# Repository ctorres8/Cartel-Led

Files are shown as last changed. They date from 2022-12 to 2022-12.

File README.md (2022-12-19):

# Cartel-Led
 Proyecto para la materia Técnicas Digitales II. Se trata de un cartel programable que pueda ser utilizado para satisfacer las necesidades básicas de un usuario, como
conocer la fecha y hora actual, la temperatura en el ambiente, o para enunciar a través de él algún mensaje para alertar o informar alguna novedad.

Va a utilizar:
* **Bluetooh:** Para enviar y recibir mensajes
* **SD:** Para recibir mensajes
* **Sensores de luz y temperatura:** Para sensor la luz del ambiente y medir temperatura.
* **RTC:** Reloj en tiempo real para tener la hora y fecha actual.
* **4 Matrices LED 8X8:** Para observar la fecha,hora, temperatura y mensajes recibidos
* **Teclado:** Para una comunicación manual con el cartel.

*El proyecto se encuentra explicado de manera más informativo en el informe (Documentación->informe)* 

# Organización del repositorio:

* **Anteproyecto:** Idea fuerza y presentación del anteproyecto.
* **Datasheets:** Hojas de datos de los componentes utilizados en el proyecto
* **Dristribución de pines:** Distribución de pines y componentes para cada integrante del grupo
* **Documentación:** Informe y manual técnico y de usuario del proyecto
* **Proyecto_Nucleo_Kicad:** Esquemáticos y diseños de PCB
* **Proyecto_STM32:** Código en C con las librerías utilzadas en el proyecto

# Videos de funcionamiento
En el siguiente link se pueden ver algunos videos cortos sobre el funcionamiento del cartel.

Link: https://drive.google.com/drive/folders/1nYiywO-ZSkL0tqdU_d7GqGv7mtErooJ5?usp=share_link

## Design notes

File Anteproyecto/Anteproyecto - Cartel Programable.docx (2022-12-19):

Anteproyecto : Cartel programable led

Idea

Se propone realizar un cartel programable led. En el mismo podrán aparecer los mensajes ingresados por el usuario, marcar la hora y la temperatura del ambiente, entre otras cosas.

Para ello utilizaremos 4 matrices led con conexión SPI de 8x8, siendo un total de 256 leds programables desde el STM.

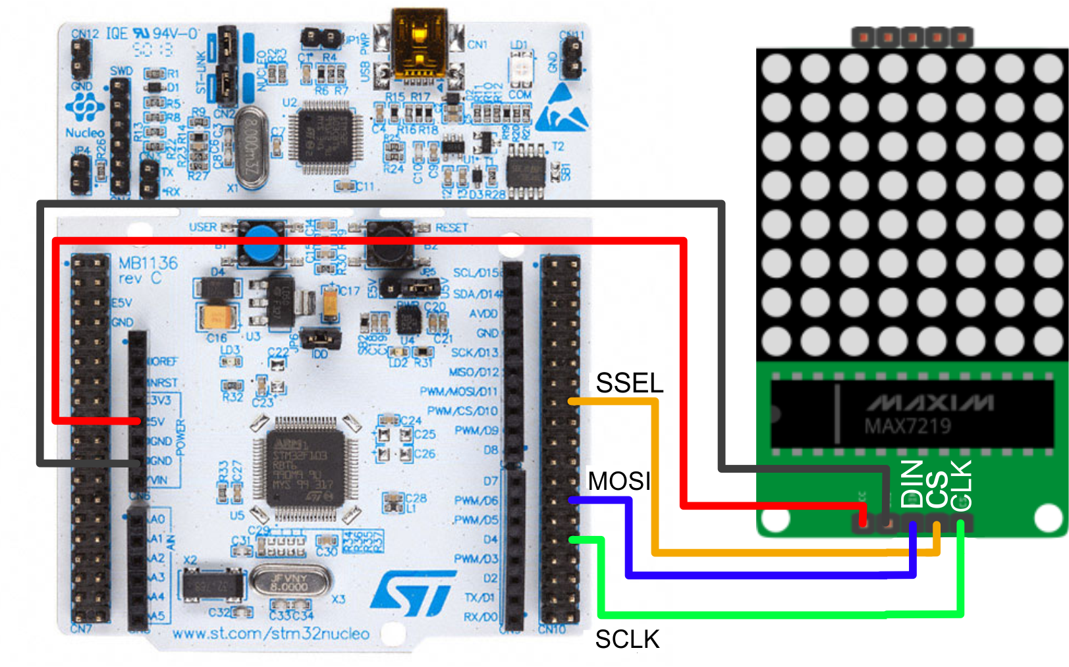
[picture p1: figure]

Los mensajes se podrán levantar desde una SD y a través de bluetooth, que se enviarán por una aplicación de android. Los módulos utilizados serán

- HC-05 para el la recepción de mensajes por Bluetooth,
- MH-SD para leer la uSD.

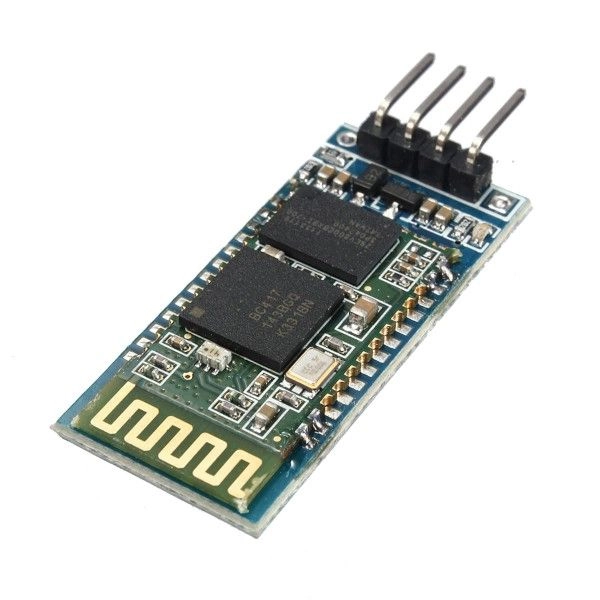
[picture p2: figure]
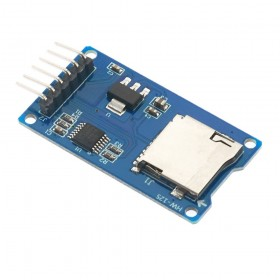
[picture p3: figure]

Módulo HC-05 Módulo MH-SD

3,3-5V 3,3-5V

El sensor para medir la temperatura del ambiente utilizado será el DHT11, DHT22 u otro conveniente que lo evaluaremos en el momento. Algunos ejemplos:

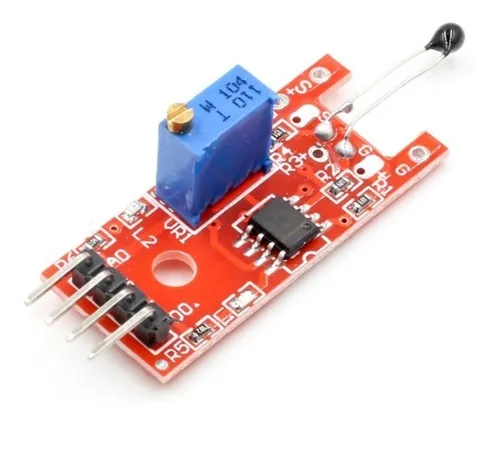
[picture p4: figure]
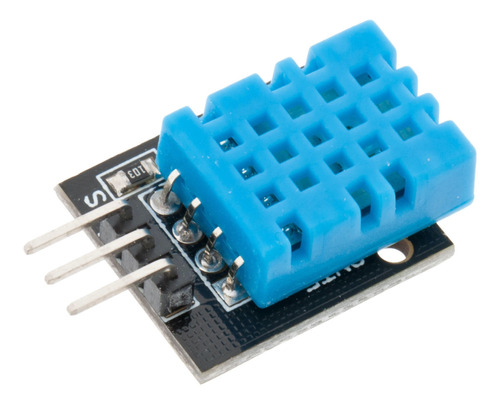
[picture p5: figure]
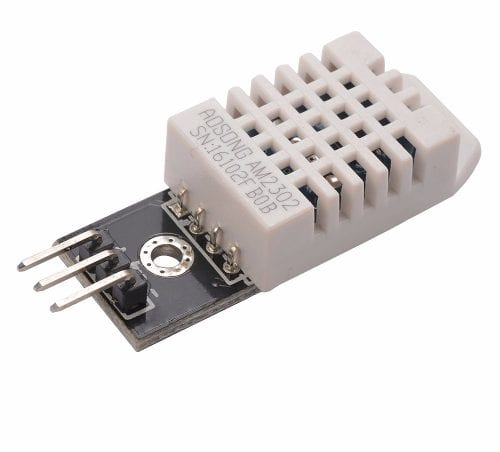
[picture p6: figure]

Sensor con LM393 DHT11 DHT22

3,3-5V 3,3-5V 3,3-5V

También se usará un sensor de luz para determinar la iluminación del ambiente. Se agrega a modo de controlar el brillo del cartel. Comunicación I2C

Módulo Sensor de Luz digital Bh1750.

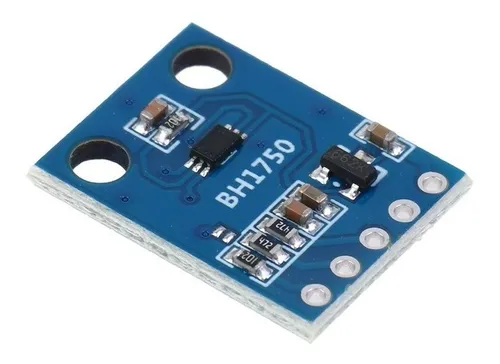
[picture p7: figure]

Bh1750

3.3-5V

Además el cartel contará con un teclado para facilitar la interacción con el usuario.

Diagrama de estados

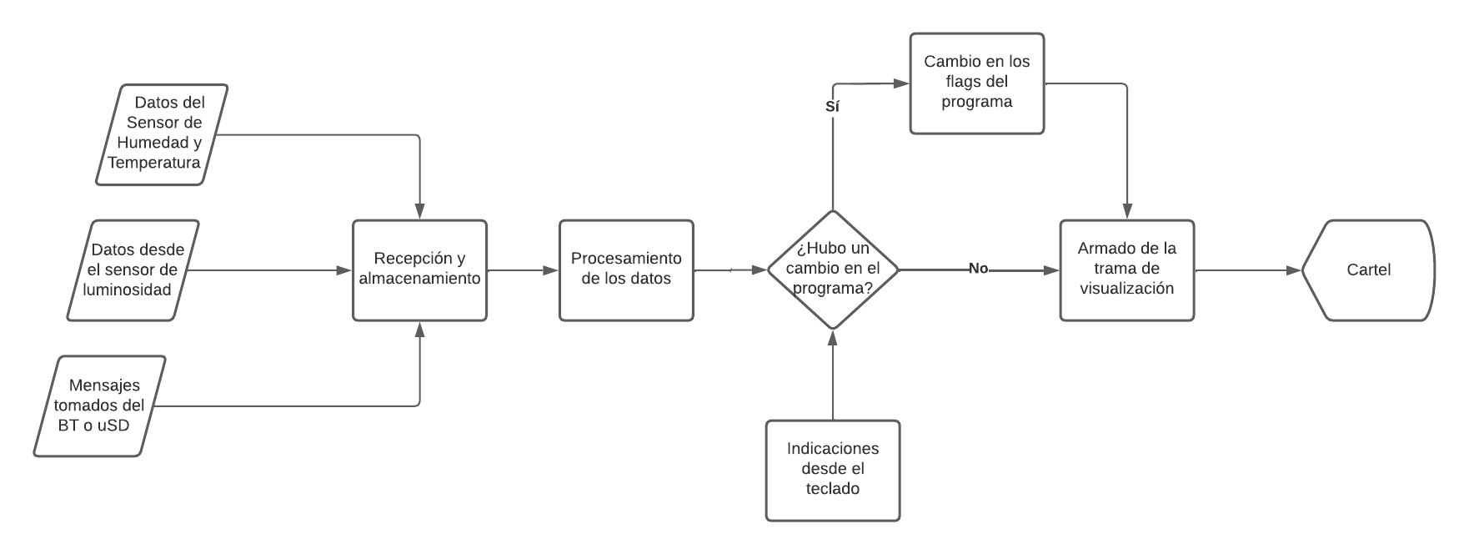
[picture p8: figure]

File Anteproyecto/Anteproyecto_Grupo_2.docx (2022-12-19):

Grupo N°: | 2 | Año y División: | 2022 - R4051
Integrantes: | | 1 – Yujra Jonathan 2 – Argani Ovidio 3 – Torres Cristian
| | | | Fecha:
Título del Proyecto: | | Cartel led programable

Descripción: (Breve explicación de las capacidades, aplicación, funciones y alcances del sistema a desarrollar para evaluar su complejidad y factibilidad de realización)

Se propone realizar un cartel programable led. En el mismo podrán aparecer los mensajes ingresados por el usuario, marcar la hora y la temperatura del ambiente.

Los mensajes se podrán levantar desde una SD y a través de bluetooth, que se enviarán por una aplicación de android.

También se usará un sensor de luz para determinar la iluminación del ambiente, a modo de controlar el brillo del cartel.

Se agregaran 3 botones para alternar desde donde se van a tomar los mensajes, elegir lo que se va a mostrar, configuración, etc.

Especificación Técnica: (Cantidad y tipo de entradas y salidas, tipo de sensores, interfaces de comunicación, interfaz de usuario, rangos de operación, recursos de hardware, funciones, etc.)

Utilizaremos 4 matrices led con conexión SPI de 8x8, siendo un total de 256 leds programables desde el STM.

Los módulos utilizados para la comunicación con SD serán el MH-SD y para el Bluetooth, el HC-05.

El sensor para medir la temperatura del ambiente utilizado será el DHT11, DHT22, LM393 u otro conveniente que lo evaluaremos en el momento

Módulo Sensor de Luz digital Bh1750. Con Comunicación I2C

La alimentación será de 5V, ya que el uC, los sensores y módulos se alimentan con ese voltaje.

Diagrama en bloques: (Diagrama en bloques del sistema con todos los módulos y su interconexión)

SENSOR

DE

TEMPERATURA

BLUETOOTH

STM32F103C8

BLUE PILL

BH1750

SENSOR

DE LUZ

I2C

Matrix 8x8 LED

TARJETA SD

SPI

SPI

Circuito de alimentación con batería

Teclados

Firma y aclaración Representante

UNIVERSIDAD TECNOLÓGICA NACIONAL FACULTAD REGIONAL Buenos Aires Departamento de Electrónica Cátedra: Técnicas Digitales II - Plan 1995 Anteproyecto

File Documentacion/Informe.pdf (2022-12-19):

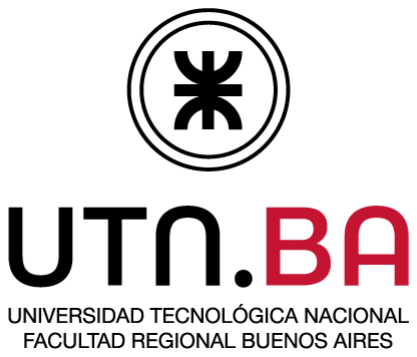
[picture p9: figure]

# Cartel Led Programable

## Trabajo práctico integrador Grupo N° 2

Materia: Técnicas digitales II Profesor: Ing. Juan Alarcón Ayudante: Ing. Marcelo Crivelli

Integrantes | Legajo
Jonathan Yujra | 163647-9
Ovidio Argani | 137715-2
Cristian Torres | 151015-0

# Índice

1. Descripción General | 3
1.1. Introducción | 3
1.2. Interfaz con el usuario | 3
1.3. Operación | 4
2. Hardware | 4
2.1. Diagrama en Bloques | 5
2.2. Circuito esquemático | 5
2.3. Descripción del Circuito | 11
2.4. Circuito Impreso | 12
3. Software | 13
3.1. Software Microcontrolador | 13
3.1.3. Librerías | 14
DEEP BLUE | 14
FatFS - Generic FAT Filesystem Module | 15
3.1.4. Programa Principal | 17
3.1.5. Rutinas de Interrupción | 19
Rutina de recepción/transmisión por Bluetooth | 19
Rutina del teclado | 21
3.1.6. Rutinas Generales | 23
Rutina de la cartel led | 23
Rutina RTC | 25
Rutina Tarjeta Sd | 26
Rutina Sensor de Temperatura y Humedad | 27
Rutina de sensor de luz digital | 28
4. Referencias | 29
Hojas de datos | 29
Manuales | 29
Librerías | 30

# 1. Descripción General

El proyecto se basa en un cartel iluminado programable por el usuario, que contará con distintas funcionalidades y con diferentes tecnologías. El cartel contará con 256 leds que se iluminarán de acuerdo a las peticiones del usuario.
El usuario podrá:
- Establecer y mostrar la fecha
- Establecer y mostrar la hora
- Mostrar la temperatura del ambiente
- Establecer, mostrar y guardar un mensaje.
- Variar la velocidad del mensaje mostrado por el cartel

Para ello, el usuario podrá comunicarse con el cartel a través de comunicación por Bluetooth o con pulsadores que formarán parte del dispositivo.

Entre las tecnologías con las que contará el cartel se encuentran:
- Comunicación Bluetooth
- Reloj en tiempo real
- Sensor de temperatura
- Tarjeta de memoria en formato SD
- Sensor de intensidad lumínica

## 1.1.Introducción

Los carteles siempre han formado y formarán parte de la sociedad. Su utilidad para enunciar un evento, alertar sobre algún peligro, informar alguna novedad son de extrema necesidad para los habitantes que pueden recurrir a ellos de forma práctica y casi al instante.

Para el proyecto de Técnicas Digitales II se propuso la creación de un cartel programable que pueda ser utilizado para satisfacer las necesidades básicas de un usuario, como conocer la fecha y hora actual, la temperatura en el ambiente, o para enunciar a través de él algún mensaje para alertar o informar alguna novedad.

## 1.2.Interfaz con el usuario

Se buscó que la interacción entre el usuario y el dispositivo sea la más práctica y cómoda posible y por eso se recurrió a una comunicación ultra instalada en el ambiente tecnológico como es el bluetooth. El usuario a través de una aplicación podrá conectarse al dispositivo e interactuar con él, ya sea para establecer algún tipo de dato (como la hora y fecha actual o algún mensaje) como también para poder pedirle al cartel que muestre esos datos, la temperatura o algún mensaje.
También se tuvo en cuenta un usuario más acostumbrado a una comunicación más analógica como pueden ser unos pulsadores. Los mismos estarán para cumplir las exigencias mínimas de las personas, como mostrar hora, fecha, temperatura o los mensajes.
El cartel estará conformado por 256 leds ubicados en forma de matriz(8x32) que mostrarán el mensaje de derecha a izquierda.
El cartel también cuenta con un sensor de luz que hará de acompañante visual, ya que elevará la iluminación del cartel si se encuentra en un ambiente demasiado iluminado (exteriores) como también reducirá la iluminación del mismo si el ambiente se encuentra oscuro (lugares cerrados, subsuelos).

## 1.3.Operación

El modo de operación es sencillo. El usuario a través de una aplicación podrá comunicarse con el cartel y enviar datos o mensajes que se reproducirá en el dispositivo. Tendrá una opción usuario normal y una pensada para trabajos de mantenimiento, donde a través de unas macro se podrán testear diferentes funciones y controlar el buen funcionamiento del mismo.

El usuario también podrá optar por usar unos pulsadores que forman parte del dispositivo para también comunicarse con él.

# 2. Hardware

Para la construcción del cartel se utilizó una placa física donde se interconectaron los diferentes sensores y módulos para el armado final del dispositivo. Entre los módulos y sensores utilizados se encuentran:

- 4x Matrix led de 8x8 puntos
- STM32 NUCLEOF401-RE
- Módulo Bluetooth HC06
- Sensor de luz BH1750
- Sensor de temperatura DHT11
- Lector de tarjetas SD

La placa física será alimentada con 5V y con un regulador de voltaje de 5V a 3,3V para alimentar algunos sensores.

## 2.1.Diagrama en Bloques

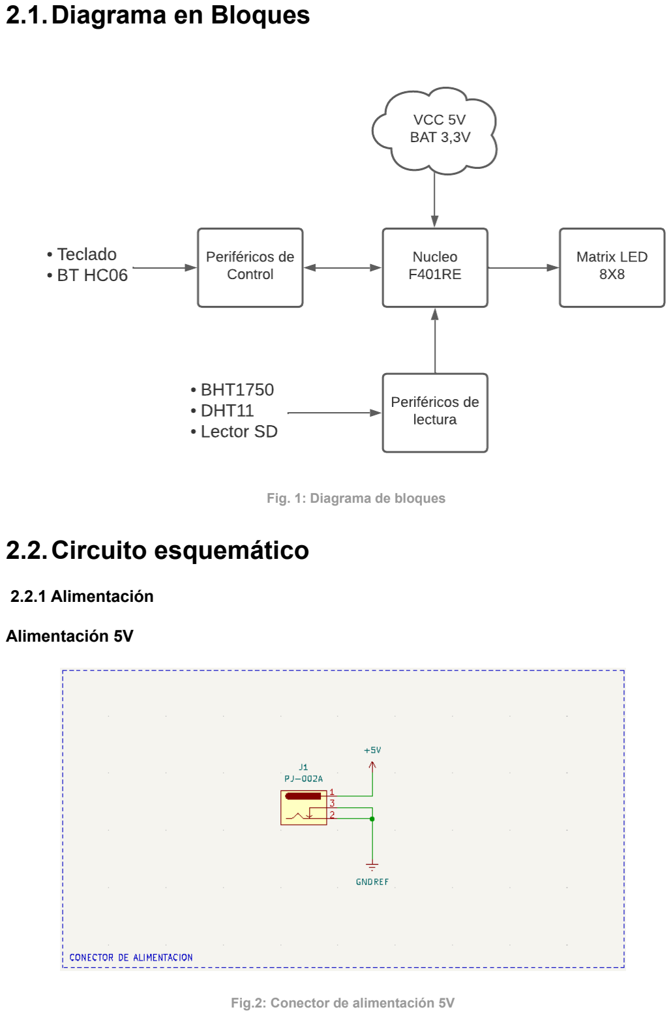
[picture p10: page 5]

Fig. 1: Diagrama de bloques

## 2.2.Circuito esquemático

### 2.2.1 Alimentación

Alimentación 5V

Fig.2: Conector de alimentación 5V

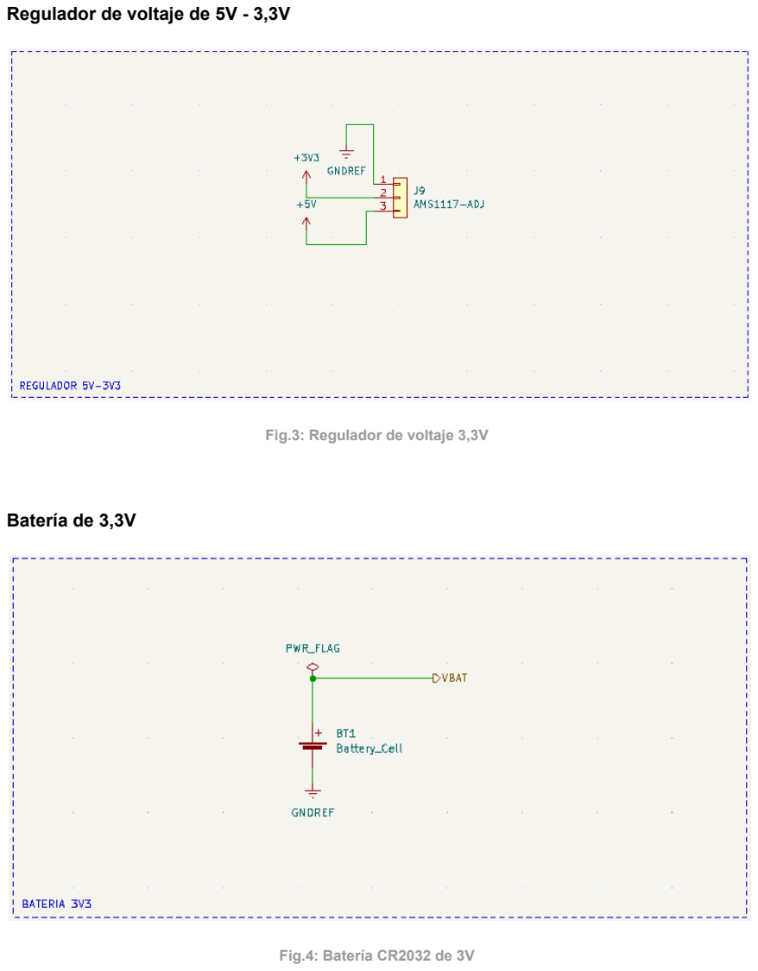
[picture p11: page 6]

Regulador de voltaje de 5V - 3,3V

Fig.3: Regulador de voltaje 3,3V

Batería de 3,3V

Fig.4: Batería CR2032 de 3V

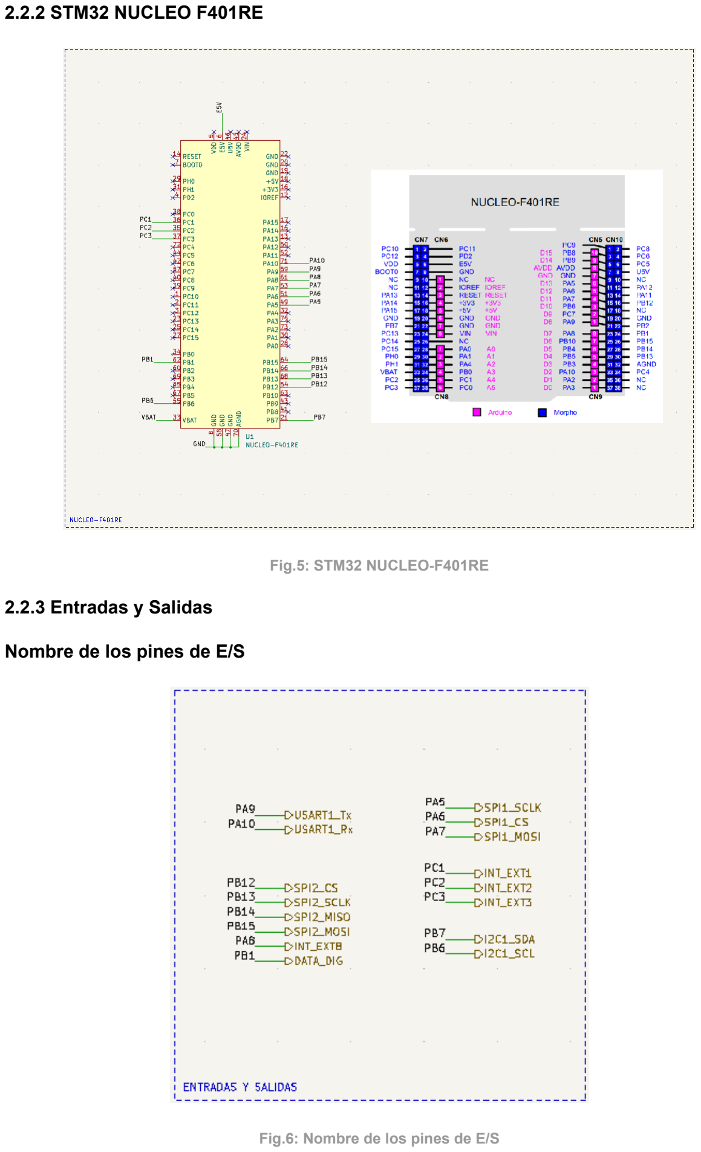
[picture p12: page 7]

### 2.2.2 STM32 NUCLEO F401RE

Fig.5: STM32 NUCLEO-F401RE

### 2.2.3 Entradas y Salidas

Nombre de los pines de E/S

Fig.6: Nombre de los pines de E/S

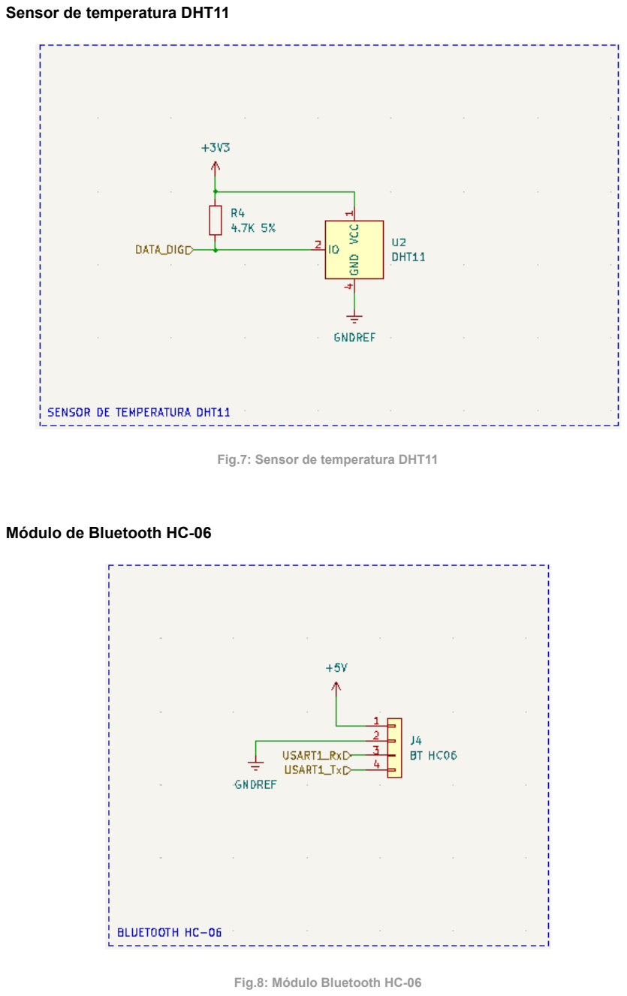
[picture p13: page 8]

Sensor de temperatura DHT11

Fig.7: Sensor de temperatura DHT11

Módulo de Bluetooth HC-06

Fig.8: Módulo Bluetooth HC-06

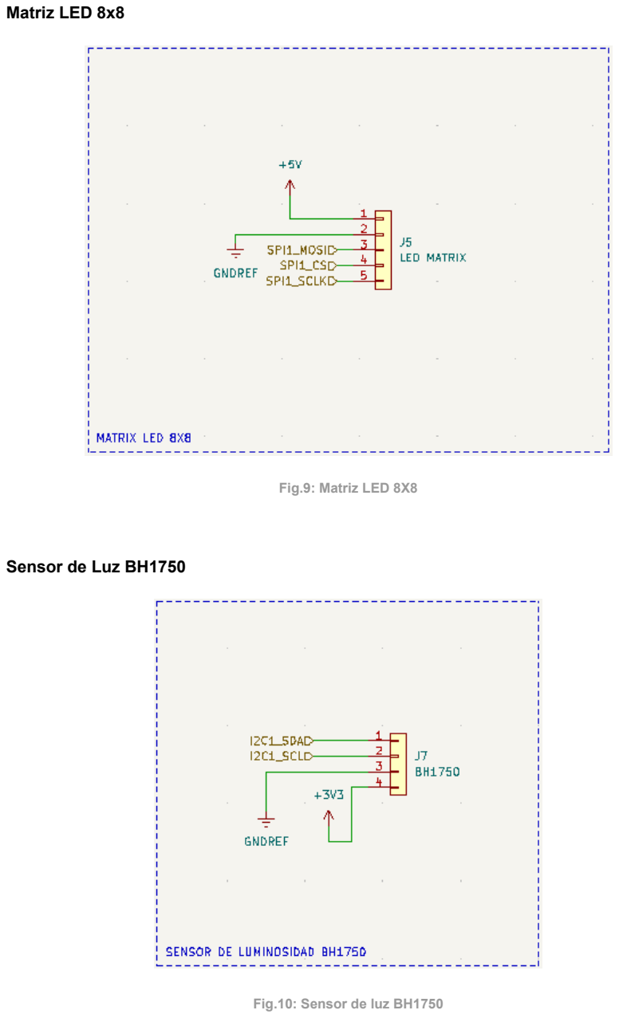
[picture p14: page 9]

Matriz LED 8x8

Fig.9: Matriz LED 8X8

Sensor de Luz BH1750

Fig.10: Sensor de luz BH1750

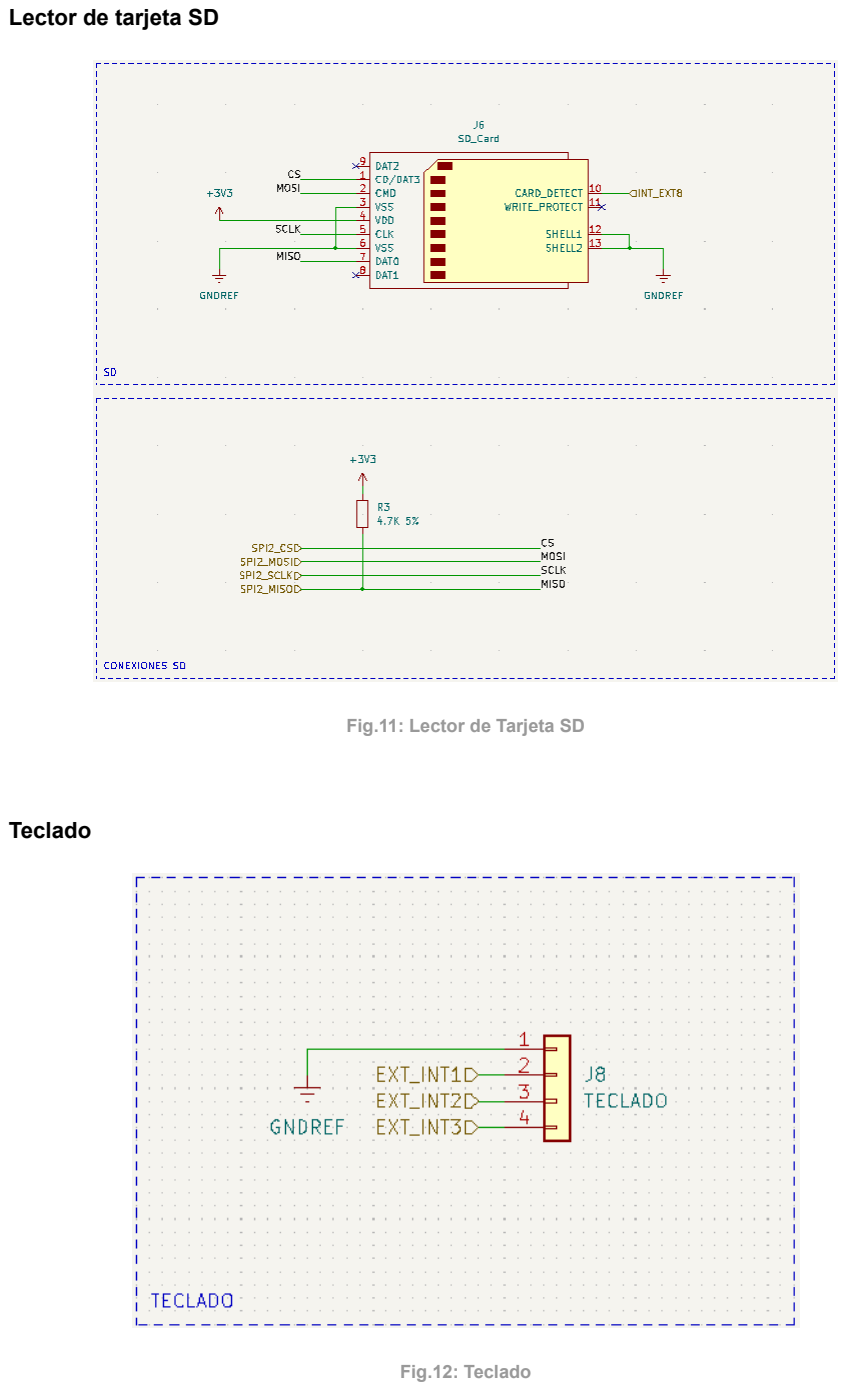
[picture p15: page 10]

Lector de tarjeta SD

Fig.11: Lector de Tarjeta SD

Teclado

Fig.12: Teclado

## 2.3.Descripción del Circuito

El circuito está alimentado por una tensión continua de 5V y también cuenta con un regulador de voltaje de 5V a 3,3V. La NUCLEO F401RE además estará alimentada por una batería de 3,3V CR2032 que servirá para alimentar las funciones básicas de la placa como el reloj en tiempo real y que de ese modo no pierda la cuenta.

La distribución de la alimentación en los componentes es la siguiente:

Los componentes alimentados a 5V son los siguientes:

- NUCLEO F401RE
- BT HC-06
- 4x Matriz LED 8X8

Los componentes alimentados a 3,3V son los siguientes:

- Lector SD
- BH1750
- DHT11

## 2.4.Circuito Impreso

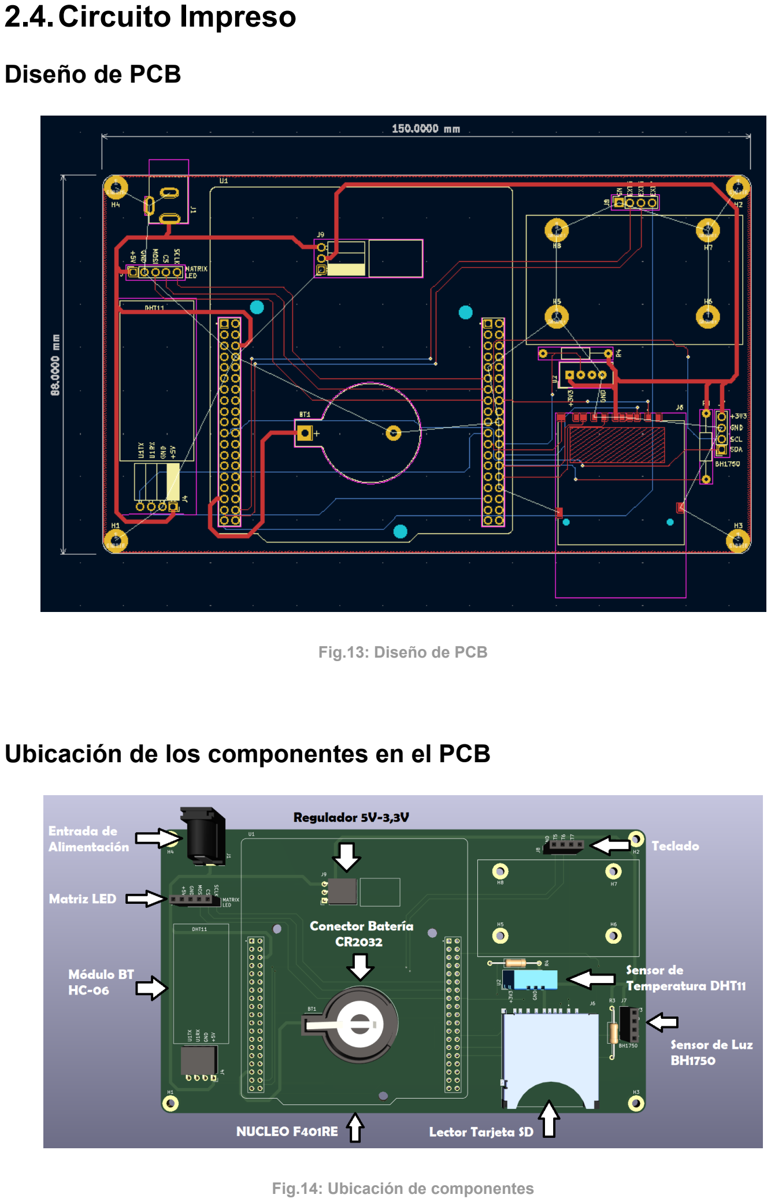
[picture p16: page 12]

### Diseño de PCB

Fig.13: Diseño de PCB

### Ubicación de los componentes en el PCB

Fig.14: Ubicación de componentes

# 3. Software

## 3.1.Software Microcontrolador

En el proyecto se utilizaron los siguientes protocolos de comunicación:

- SPI para la comunicación con la SD y la matrix LED
- I2C para la comunicación con el sensor de luz BH1750 y el sensor de temperatura DHT11
- Comunicación Serie para la comunicación con el módulo de BT HC06.

Cada uno de los módulos tuvo sus pines dedicados para asegurar la correcta transferencia de información.

Para el manejo de tiempo se utilizaron timers y RTC. El RTC para guardar la fecha y hora en el micro, teniendo en cuenta de que estas no se pierdan en caso de que el micro sea desconectador la tensión de alimentación ya que está también alimentado por una batería externa.

Se utilizaron Timers para controlar:

- Sistema operativo (FreeRTOS)
- DHT11
- Rutina de la Matrix Led

El teclado cuenta con 3 botones que fueron configurados como interrupciones externas.

El diagrama principal se encuentra en el apartado 3.1.4.

### 3.1.1. Entorno de desarrollo

El proyecto fue enteramente desarrollado en el IDE que nos provee ST, el STM32CUBE IDE y el lenguaje de programación utilizado fue en su totalidad el C.

### 3.1.2. Sistema Operativo

Se utilizó un sistema operativo en tiempo real (FREERTOS) por su practicidad con los manejos de tarea ya que su planificador es del tipo preemtive, los que nos permite organizar las tareas según su prioridad.

El RTOS (y su planificador) cuenta con un timer dedicado a que se ejecute su planificación.

### 3.1.3. Librerías

DEEP BLUE

Se utilizaron librerías externas para el módulo de matriz Led 8x8 y el IC MAX7219, dichas librerías fueron realizadas para la gente de DEEP BLUE.

DOT_MATRIX.h

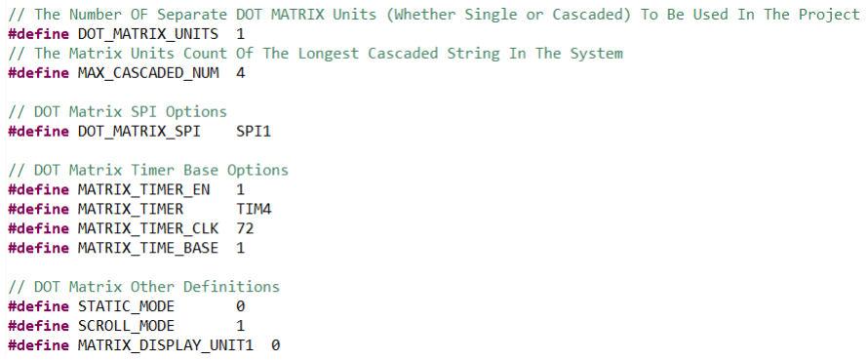
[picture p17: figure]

Fig.15: Bloque de código DOT_MATRIX.h

En la imagen de arriba se observan los diferentes defines donde se configura la cantidad de módulos en cascada, el número de SPI de la placa NUCLEO y el timer de interrupción.

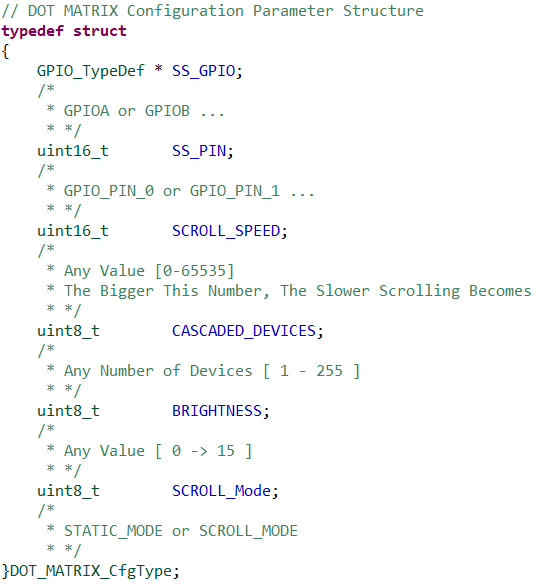
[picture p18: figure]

Fig.16: Struct de configuración de los módulos Matriz Led

Dentro de la estructura DOT_MATRIX_CfgType se pueden administrar la velocidad de corrimiento, la iluminación y los pines dedicados.

Las prototipos de funciones de la librería encargada administrar la funciones internas de del módulo son las siguientes:

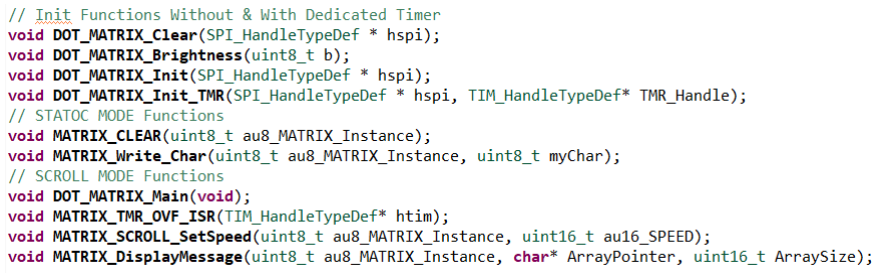
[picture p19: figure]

Fig.17: Prototipos de funciones utilizados en la librería

En la siguiente variable del tipo struct perteneciente a DOT_MATRIX_cfg.c se define el pin de Chip Select, la velocidad inicial (en milisegundos) y el brillo por defecto.

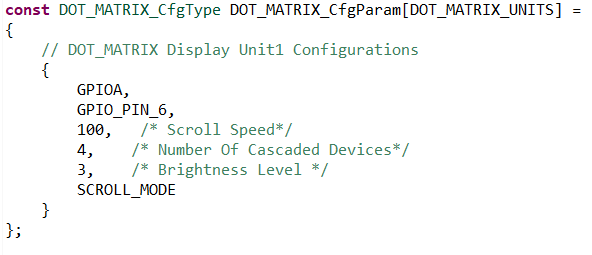
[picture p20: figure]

Fig.18: Configuración Default de los módulos Matriz Led

Los enlaces a las librerías se encuentran en el apartado de referencias.

Alexander Hoffmanes

La librería externa del BH1750 creada por Alexander Hoffmanes, es sencilla. De ella usamos la inicialización del sensor de luz digital:

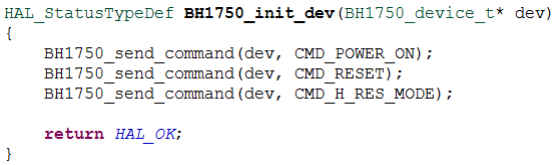
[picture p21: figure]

En donde se envían comandos por I2C para configurar el sensor a una resolución de 1 lux.

Luego para las mediciones usamos la función:

La cual lee el valor sensado por el módulo BH1750, luego lo convierte a unidades de lux.

FatFS - Generic FAT Filesystem Module

FatFs es un módulo de sistema de archivos FAT/exFAT genérico para pequeños sistemas integrados. Está escrito totalmente en C y en una capa completamente separada de la capa de E/S del disco. Fue desarrollada por chaN.

FatFs controla los dispositivos de almacenamiento a través de una sencilla interfaz de acceso a los medios que se muestra a continuación.

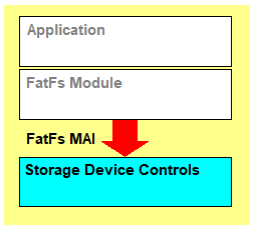
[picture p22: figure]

Fig.19: Abstracción de la librería

Las librerías que incluye el paquete son:

- diskio.h: Encargada de la interfaz de disco de bajo nivel (E/S)
- ff.h: módulo de archivos de sistema FAT
- ffconf.h: Configuraciones funcionales FatFs

Los archivos .C que incluye el módulo son:
- ff.c: código del módulo de archivos de sistema FAT
- ffsystem.c: código de funciones dependientes del SO para FATFs
- ffunicode.c: tablas de conversión para diferentes lenguajes.
- mmc_stm32f1_spi.c: código de control del modo SPI

El enlace a la librería se encuentra en el apartado de referencias.

### 3.1.4. Programa Principal

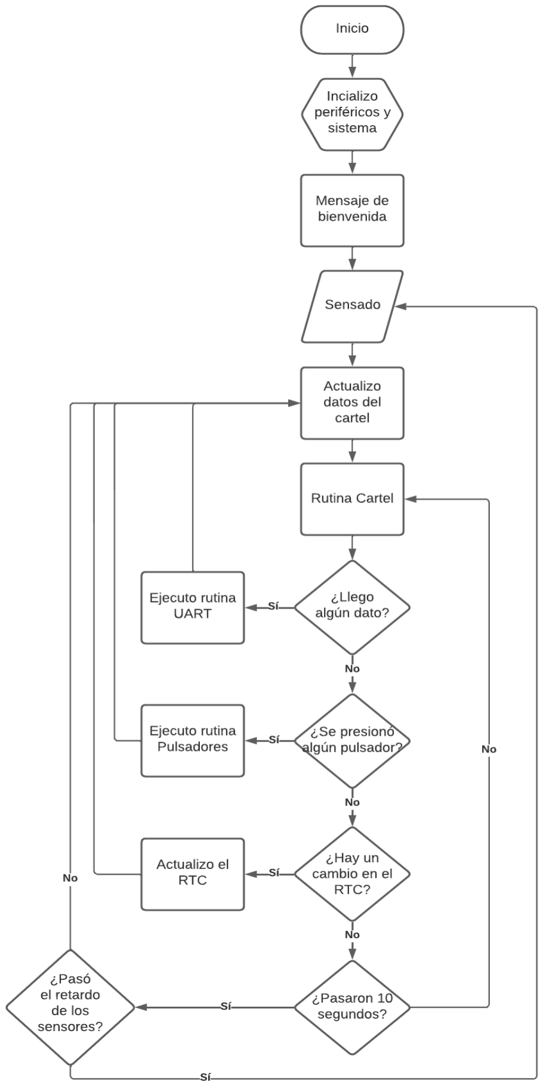
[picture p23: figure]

Fig.20: Diagrama de flujo general del sistema

El programa está enteramente diseñado en freertos, que tiene la particularidad de ejecutar un número prediseñado de tareas al mismo tiempo, por lo que el diagrama de flujo de arriba es una aproximación de lo que sucede en realidad. Al ejecutarse las tareas por orden de prioridad y al tener cada una un tiempo de ejecución distinto es difícil pensar en que el sistema tenga algún tipo de previsibilidad.

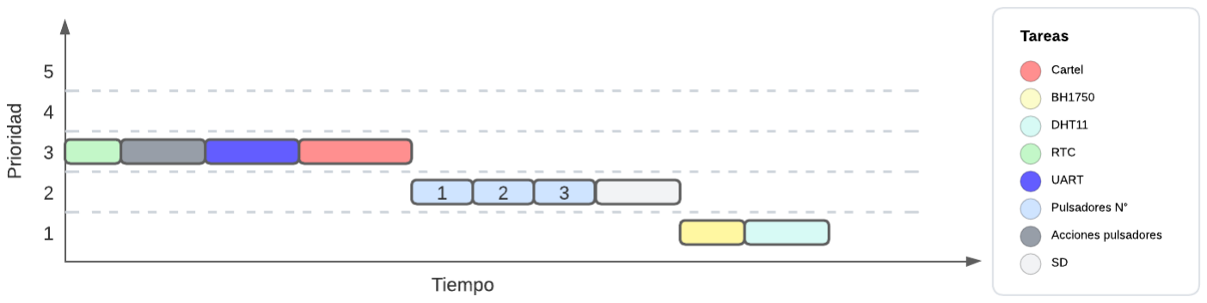
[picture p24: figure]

Fig.21: Diagrama de prioridad

En la imagen de arriba se ve como fue diseñado el planificador y la prioridad que se le dio a las tareas. Cabe destacar que la más importantes para nuestro criterio fueron:
- Tarea Cartel: donde se encarga de la manipulación de los mensajes en la matriz led
- Tarea UART: donde una vez recibido el mensaje por bluetooth se procede a separarlo y darle una función dependiendo del mensaje recibido.
- Tarea RTC: donde el reloj actualiza la hora y fecha actual.


Fig.22: Inicialización de tareas

En la imagen de arriba se puede observar la inicialización de tareas del RTOS cuyo orden de prioridad decrece a medida que el número de prioridad crece.


Fig.23: Inicialización de periféricos

### 3.1.5. Rutinas de Interrupción

Rutina de recepción/transmisión por Bluetooth

Fig.24: Diagrama de flujo tarea Bluetooth

La rutina de recepción por Bluetooth se hace en forma de interrupción y a través de comunicación serie. Cuando llega un nuevo mensaje el programa deja lo que está haciendo y va a atender el pedido de iniciar la recepción del mensaje. Mientras recibe, sigue ocupándose en las demás tareas. La HAL encargada de administrar eso es:

La HAL recibe 3 parámetros:
- El puntero a la uart
- El vector donde se van a guardar los datos
- Y el valor máximo de recepción.

HAL_UARTEx_ReceiveToIdle_IT permite recibir una cantidad máxima de datos predefinida en el parámetro Size, como también si llega a un estado Idle (es decir, porque el largo de la trama era mucho más chico que el valor máximo propuesto y encontró un fin de cadena en el medio), también puede cortar la recepción y avisar que terminó de recibir.

Una vez terminado de recibir los datos, dependiendo del tipo de mensaje recibido, el micro puede:
- Actualizar el valor de la hora y fecha en el RTC.
- Devolver un mensaje si lo que se está pidiendo es algún dato.
- Guardar un mensaje enviado por el usuario.

Rutina del teclado


Fig.25: Diagrama de flujo tarea teclados

El teclado consiste en tres pulsadores conectados a la NUCLEO F401RE en forma de interrupción externa. Cada pulsador tiene su propia tarea y sub rutina encargado de modificar algún aspecto que afecte a lo que se muestra en la matriz de led.

Subrutina pulsador 1:
El pulsador 1 uno controlará los modos en que se mostrarán los datos en el cartel.
- El modo normal, el cartel mostrará la fecha, la hora y la temperatura cada 10 segundos, cada uno
- Si se presiona una vez, el cartel mostrará solo la fecha ininterrumpidamente.
- Si se presiona por segunda vez, el cartel mostrará solo la hora ininterrumpidamente.
- Si se presiona por tercera vez, el cartel mostrará solo la temperatura ininterrumpidamente.
- Si se vuelve a presionar volverá al modo normal

Subrutina pulsador 2:
El pulsador 2 mostrará el mensaje cargado en el dispositivo a través del bluetooth o del SD.
- Si se presiona una vez, el cartel mostrará el mensaje cargado por el Bluetooth.
- Si se presiona por segunda vez, el cartel mostrará el mensaje cargado por el SD.
- Si se presiona por tercera vez, el cartel volverá al modo normal.

Subrutina pulsador 3:
El pulsador 3 variará la velocidad en la que los datos se desplazan en el cartel.
- Si se presiona una vez, el cartel tendrá una velocidad baja.
- Si se presiona por segunda vez, el cartel tendrá velocidad media.
- Si se presiona por tercera vez, el cartel tendrá velocidad alta.
- Si se vuelve a presionar, volverá a velocidad baja.

### 3.1.6. Rutinas Generales

Rutina de la cartel led


Fig.26: Diagrama de flujo tarea cartel led

El cartel led se actualiza cada cierta cantidad de milisegundos, cuando termina este tiempo, el mensaje del cartel se desplaza una posición a la izquierda. La función encargada de este desplazamiento es:

Cuando se modifica el mensaje a mostrar se apagan todos los leds de los módulos y empieza a escribir el nuevo mensaje por medio de la función. La función que apaga los leds de los módulos es:

Si se presiona el pulsador 3 cambia la velocidad del desplazamiento del cartel.

Rutina RTC


Fig.27: Diagrama de flujo tarea RTC

El RTC se encarga de mantener la cuenta de la hora y fecha actual en todo el sistema. Aún si el dispositivo se encuentra desenchufado, el RTC sigue funcionando debido a que está siendo alimentado por una batería CR2032.

Su funcionamiento es simple y casi imperceptible, cuenta segundos,minutos,horas y fechas. Cuando ocurre algún cambio, actualiza los datos del cartel. Su cuenta puede ser modificada o actualizada a través del Bluetooth.

Rutina Tarjeta Sd


Fig.28: Diagrama de flujo tarea SD

Cuando el usuario seleccione este modo se tendrá que chequear si hay una tarjeta sd insertada, caso contrario se pedirá por el cartel que se inserte una. Si hubiera tarjeta insertada se procede a inicializar y pasar a modo sd.

Cuando se encuentre en el modo sd los mensajes se cargaran a partir de la tarjeta sd. Los mensajes estarán alojados dentro de un archivo llamado "mensajes.txt". La particularidad de este modo es que los mensajes del usuario contenidos dentro del archivo se cargarán de forma cíclica.

Por ejemplo: Si tuviera un solo mensaje, sería el único en mostrarse. Pero, si tuviera dos o más, se mostraran de a uno con una duración predeterminada, y siempre de forma cíclica. Se considera un mensaje a una línea del archivo de texto. El modo sd se encarga automáticamente de actualizar el buffer del cartel.
A continuación un ejemplo del contenido del archivo.

Fig.29: Creación de mensajes

En el caso de que se retire la tarjeta o se cambie de modo se retorna al estado inicial.

Rutina Sensor de Temperatura y Humedad


Fig.30: Diagrama de flujo tarea Sensor de temperatura DHT11

El sensor DHT11 es un dispositivo que capta la temperatura y la humedad del ambiente. Su forma de recibir es en formato serie, empezando por la humedad y luego por la temperatura.

La comunicación entre el microprocesador y el DHT11 y su sincronización se hace a través de un solo bus de datos de 40bits.

El formato de datos es:

8 bits de datos de humedad para enteros + 8 bits de datos de humedad para decimales + 8 bits de datos enteros de temperatura + 8 bits de datos decimales de temperatura + 8 bits de paridad.

La inicialización del DHT11 se hace a través de:

Las lecturas se hacen a través de de la tarea DHT11 con la función:

Rutina de sensor de luz digital


Fig.31: Diagrama de flujo tarea sensor de luz BH1750

La rutina del sensor de luz BH1750 se ejecuta por medio de la comunicación I2C cada 10 segundos, la función encargada de leer el valor y convertirlo a unidades de lux es:

En esta función se ejecutan 2 funciones más:

- BH1750_read_dev(dev): Se encarga de leer 2 bytes que sensa el módulo BH1750
- BH1750_convert(dev): Se encarga de unir los 2 bytes y dividirlo por 1,2 para convertirlo a lux

Una vez que terminó de convertir a unidades de lux, se determina el brillo de la matriz led:

- Si la iluminación es alta, el brillo de la matriz será alta
- Si la iluminación es baja, el brillo de la matriz será baja

La configuración de la intensidad del brillo se hace mediante la función:

DOT_MATRIX_Brightness(i); // Siendo i un valor del 1 al 10

# 4. Referencias

Hojas de datos

Sensor de luz BH1750: Link Datasheet (https://drive.google.com/file/d/1hNUBCfKHLAi73L5wXrpIC9SqpSZIVXO_/view?usp=share_link)

Sensor de temperatura DHT11: Link Datasheet (https://drive.google.com/file/d/1Tri0Ij8wTlMghaLgcgkP-QxAEPVwCSko/view?usp=share_link)

Módulo Bluetooth: Link Datasheet (https://drive.google.com/file/d/1JlVVr95fDBjWHLqKieN57tqQwmHvouif/view?usp=share_link)

Regulador de tensión LM1117: Link Datasheet (https://drive.google.com/file/d/1GX2ReR8_QrMDlmroXhPoYFuI4F_l6q0y/view?usp=share_link)

Matriz Led 8x8: Link Datasheet (https://drive.google.com/file/d/1PQreYGPisMozHs944OEVEkRimML9rfyi/view?usp=share_link)

IC Max7219: Link Datasheet (https://drive.google.com/file/d/1aTzSAUG9kioTlt8-OvNlfmLg9X7Mt-0M/view?usp=share_link)

SD: Link Datasheet (https://drive.google.com/file/d/1bB_GbcPMbwC02TCU_5XH0IdrR9Pr8sX0/view?usp=share_link)

Manuales

STM32 NUCLEO F401RE: Reference Manual (https://drive.google.com/file/d/1pSwSPJOKQf2tx9QKM_nUZqD4yKAoJSJ0/view?usp=share_link)

STM32 NUCLEO F401RE: User Manual (https://drive.google.com/file/d/1CUA2DkAZa6mUlTmTVMNTtc7Z68Vzk2mZ/view?usp=share_link)

Librerías

Deep Blue Librería y proyecto: Link WEB (https://deepbluembedded.com/stm32-max7219-dot-matrix-display-interfacing-library/) Librería Descarga: Link Descarga (https://drive.google.com/file/d/17-EFMTJjTC_MbU3OdnbpxqhBEf7X1ldC/view) Proyecto ChaN FATFS: Link WEB (http://elm-chan.org/fsw/ff/00index_e.html)

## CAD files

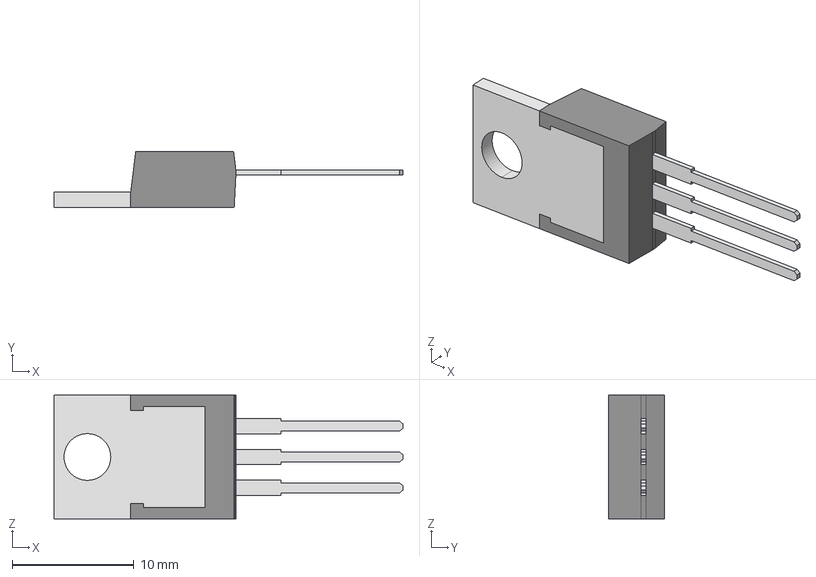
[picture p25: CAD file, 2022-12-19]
Proyecto_Nucleo_KiCAD/modelos3d/LM1117T.stp
28.7 x 4.57 x 10.2 mm
T03B_BODY
T03B_LEAD x 3
T03B_HS

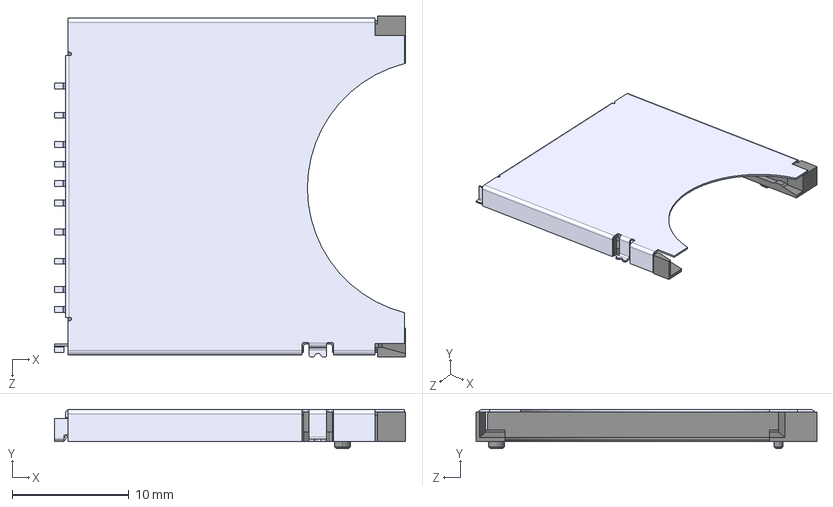
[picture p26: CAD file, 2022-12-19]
Proyecto_Nucleo_KiCAD/modelos3d/3D_SD_GSD09002SEU.step
30.1 x 3.35 x 29.2 mm

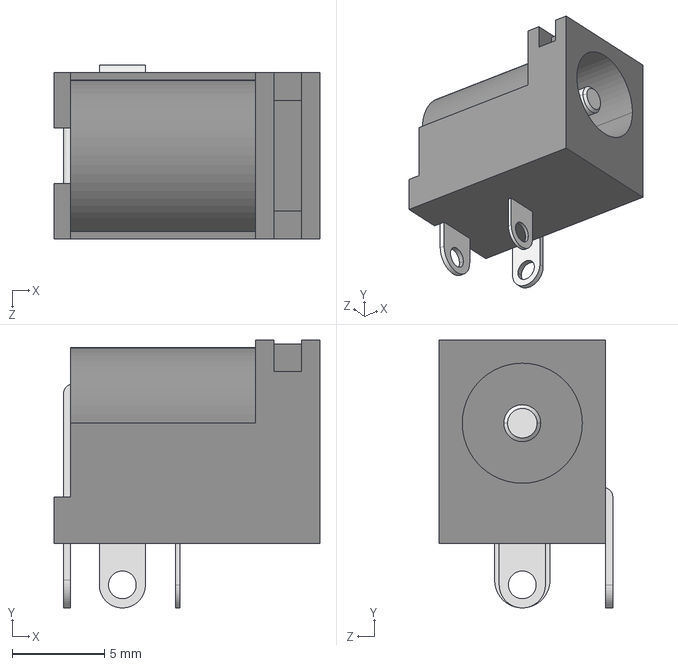
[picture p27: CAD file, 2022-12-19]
Proyecto_Nucleo_KiCAD/modelos3d/PJ-002A.step
14.4 x 14.5 x 9.40 mm

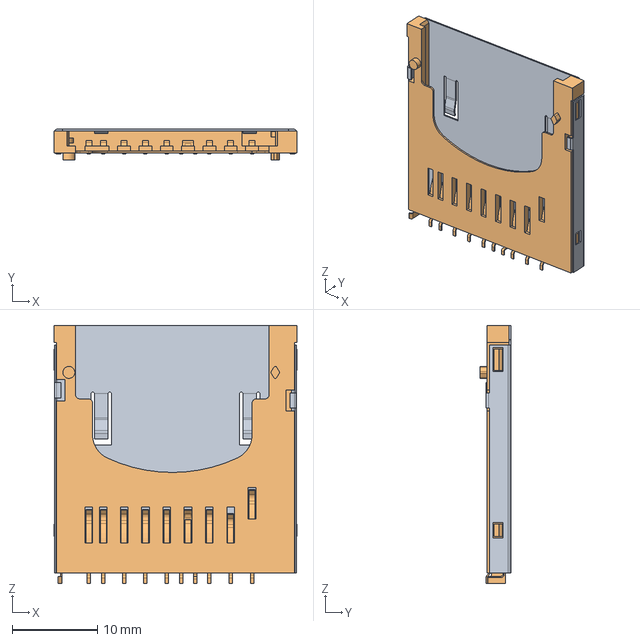
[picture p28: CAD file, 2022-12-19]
Proyecto_Nucleo_KiCAD/modelos3d/10067847-001RLF.stp
28.4 x 3.60 x 30.3 mm
PRT0003
PRT0005

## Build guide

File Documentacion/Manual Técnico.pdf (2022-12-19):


# Cartel Led Programable

## Manual Técnico

Técnicas Digitales II

Integrantes

Jonathan Yujra

Ovidio Argani

Cristian Torres

# Índice

1. Herramientas necesarias | 3
2. Consideraciones de seguridad | 3
3. Diagramas | 4
3.1 Diagrama de bloques | 4
3.2 Esquemáticos | 4
3.3 Ubicación de los componentes en la placa | 10
4. Características Eléctricas | 10
5. Solución de problemas | 11
6. Soporte técnico | 12

# 1. Herramientas necesarias

Para el armado/desarmado del dispositivo y su posterior arreglo es necesario que cuente con las siguientes herramientas.

- Destornillador
- Multímetro
- Soldador
- Desoldador
- Fuente de 5V
- Cable microUSB a USB
- etc.

# 2. Consideraciones de seguridad

Antes de desarmar el dispositivo verifique que se encuentra desconectado a la red eléctrica.

No lo sacuda, podría desconectar los módulos que tiene dentro.

El dispositivo cuenta con una batería interna que alimenta al microcontrolador, antes de analizar el estado de los componentes es posible que tenga que retirar la batería para evitar algún falso contacto.

El dispositivo cuenta con una placa de desarrollo y varios módulos, cada uno se encuentra señalado en la placa, al igual que el pin por donde entra su correspondiente alimentación. Si necesita medir tensión ubique primeramente los pines señalados en la placa.

Tenga en cuenta que el dispositivo no cuenta con ningún tipo de interruptor, una vez que sea conectado a la red eléctrica el dispositivo quedará alimentado.

El dispositivo recibe 5V de tensión de entrada, no lo alimente con otro tipo de tensión, podría dañar los componentes.

# 3. Diagramas

## 3.1 Diagrama de bloques

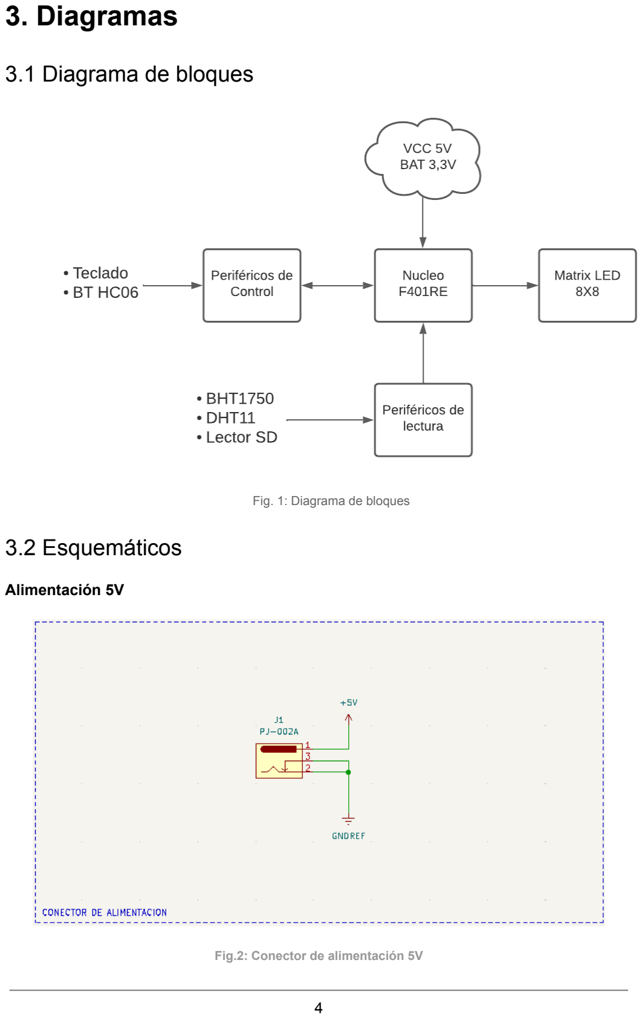
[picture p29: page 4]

Fig. 1: Diagrama de bloques

## 3.2 Esquemáticos

Alimentación 5V

Fig.2: Conector de alimentación 5V

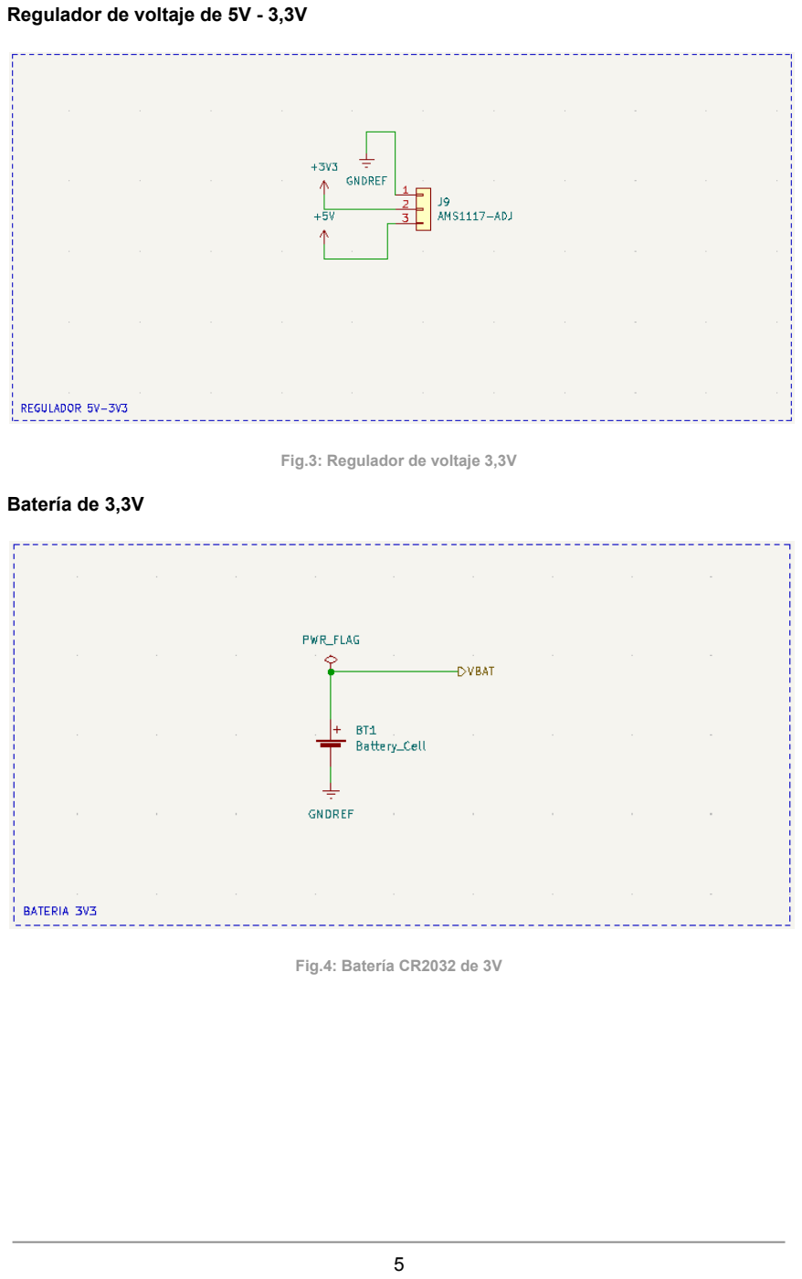
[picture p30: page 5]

Regulador de voltaje de 5V - 3,3V

Fig.3: Regulador de voltaje 3,3V

Batería de 3,3V

Fig.4: Batería CR2032 de 3V

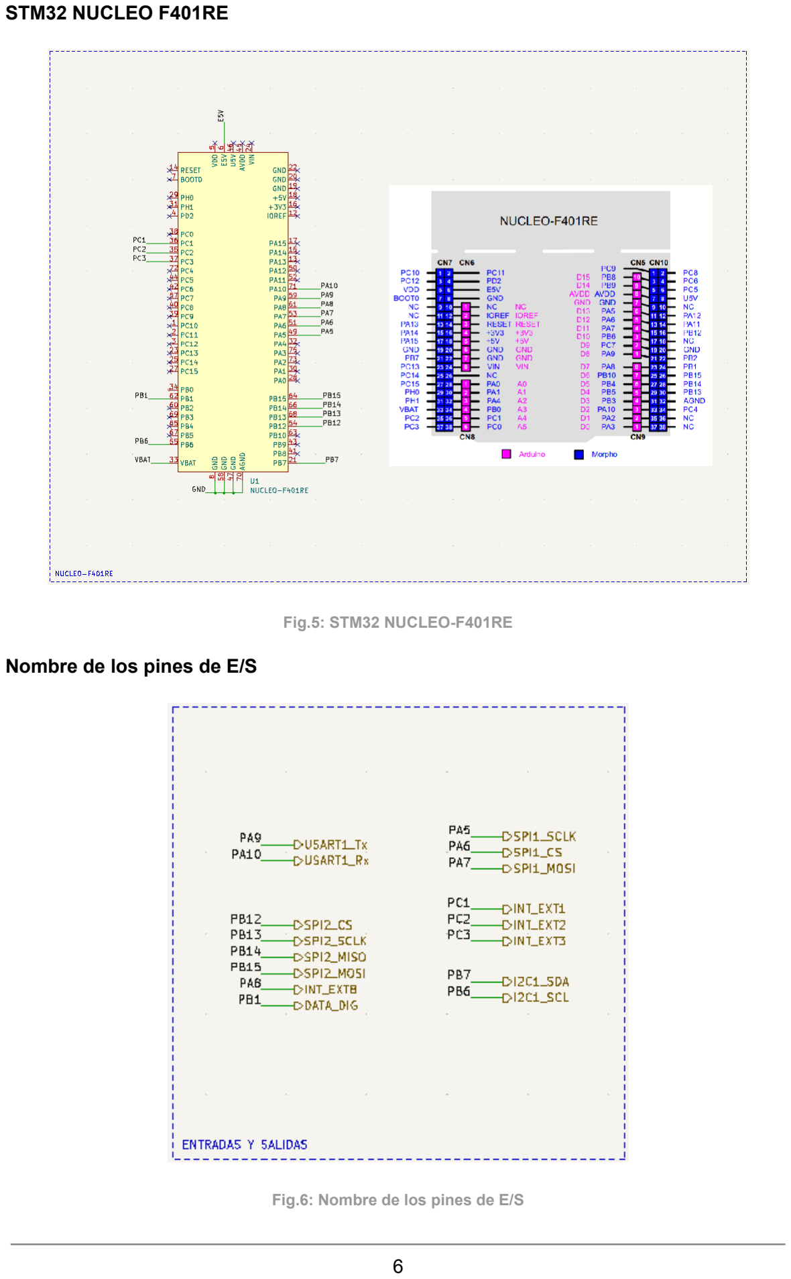
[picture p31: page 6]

STM32 NUCLEO F401RE

Fig.5: STM32 NUCLEO-F401RE

Nombre de los pines de E/S

Fig.6: Nombre de los pines de E/S

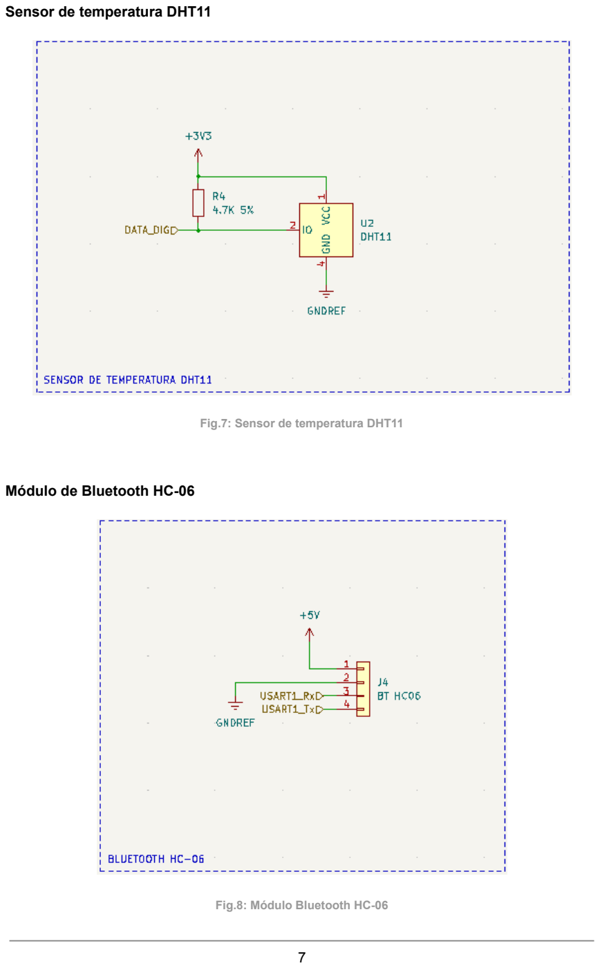
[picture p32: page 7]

Sensor de temperatura DHT11

Fig.7: Sensor de temperatura DHT11

Módulo de Bluetooth HC-06

Fig.8: Módulo Bluetooth HC-06

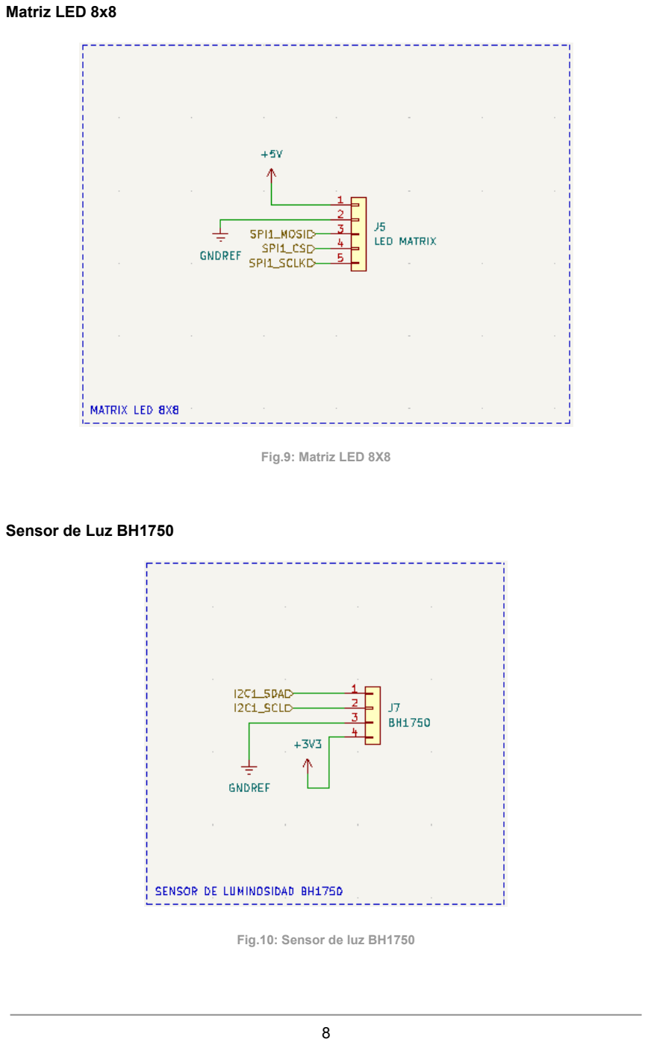
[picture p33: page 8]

Matriz LED 8x8

Fig.9: Matriz LED 8X8

Sensor de Luz BH1750

Fig.10: Sensor de luz BH1750

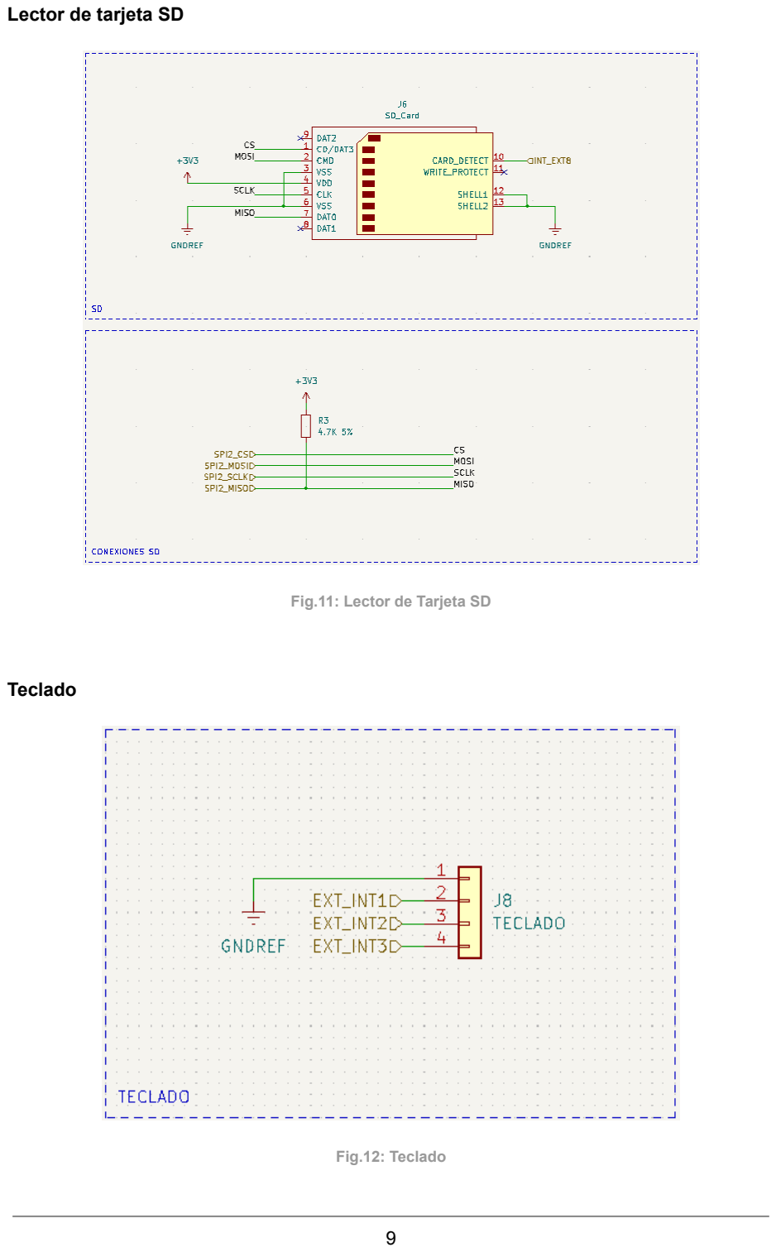
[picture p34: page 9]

Lector de tarjeta SD

Fig.11: Lector de Tarjeta SD

Teclado

Fig.12: Teclado

## 3.3 Ubicación de los componentes en la placa

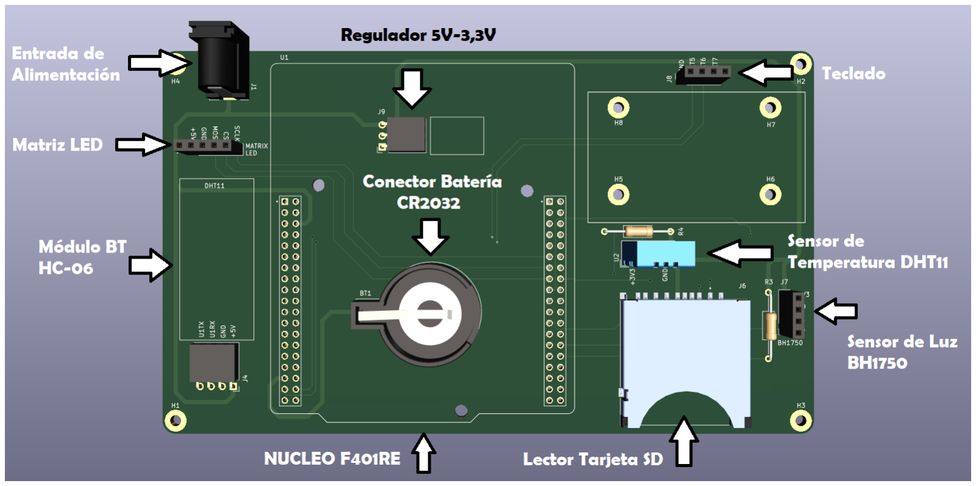
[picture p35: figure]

Fig.13: Ubicación de componentes

# 4. Características Eléctricas

### Valores máximos

Componente | Tensión [V] | Corriente[mA]
Matriz Led | 6 | 500
BH1750 | 4,5 | 7
Regulador LM1117 | 20 | 800
DHT11 | 5,5 | 0,3
Lector SD | 3,6 | 200
BT HC-06 | 5,2 | 40
Corriente Maxima Consumida | | 1547,30 mA

### Valores Normales

Componente | Tensión [V] | Corriente[mA]
Matriz Led | 5V | 330
BH1750 | 3,3V | 0,2
Regulador LM1117 | 5V | 5
DHT11 | 3,3V | 0,1
Lector SD | 3,3V | 100
BT HC-06 | 5V | 8
Corriente media | | 443mA

# 5. Solución de problemas

No funciona el sensor o algún módulo en particular. Verifique que esté recibiendo el voltaje correspondiente.

Se pierde la cuenta del reloj cuando se desenchufa de la red.
Es posible que la batería se haya quedado sin carga, cámbiela.

Los pulsadores no presionan de manera correcta.
Es posible que estén obstruidos o por hayan sido aplastados con fuerza, cámbielos.

El Lector SD no funciona de manera correcta.
Es posible que se haya presionado con fuerza y que se haya desoldado, verifique su soldadura.

El sensor de temperatura no funciona correctamente.
Es posible que haya estado expuesto a altas temperaturas, verifique si sus voltajes son óptimos.

### Comandos de testeo

Los siguientes comandos de testeo sirven para configurar y comprobar el buen estado del sistema. Puede enviar los comandos por la aplicación ATYAPP o enviarlos a través de un puerto serie.

Comando | Función
ATYO | Devuelve un OK por BT.
ATYM | Devuelve el último mensaje de anuncio cargado en el cartel
ATYFdd-mm-aaaa | Configura la fecha dd/mm/aaaa en el cartel
ATYHhh:mm:ss | Configura la hora hh:mm:ss en el cartel
ATYf | Devuelve la fecha por BT
ATYh | Devuelve la hora por BT
ATYT | Devuelve la temperatura que marca el sensor por BT

Enviar los comandos a través de la aplicación ATYAPP:
Para enviar los comandos a través de la aplicación ATYAPP puede escribir los comandos en el sector de mensajes. Siguiendo los siguientes pasos:
1. Asegúrese que el módulo HC-06 se encuentra conectado.
2. Verifique si el dispositivo se encuentra alimentado a 5V.
3. Conéctese al dispositivo a través de la aplicación ATYAPP
4. Escriba el comando en el sector de mensajes y presione ENVIAR.

Enviar los comandos a través del puerto serie:
Para enviar los comandos a través del puerto serie debe utilizar los pines USART1 TX (D8) y para recibir una respuesta USART1 RX (D2). Como están señalados en la imagen de abajo:

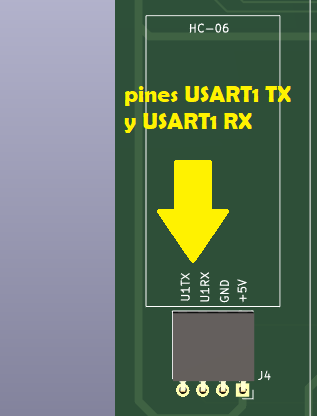
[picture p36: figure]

Fig. 14: Ubicación de los pines USART1 TX Y USART1 RX

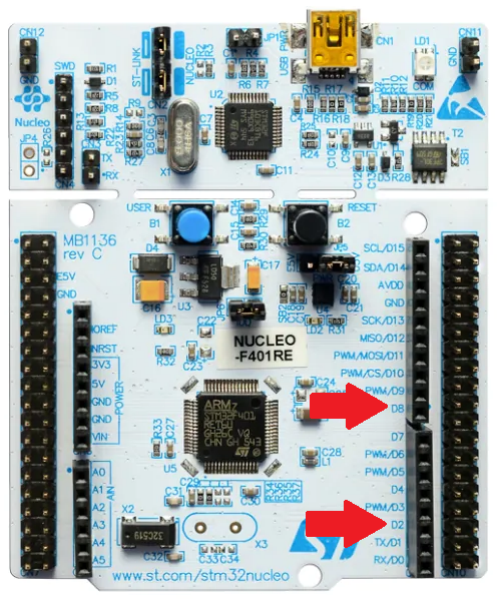
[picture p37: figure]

Fig. 15: Ubicación de los pines (D8) USART1 TX Y (D2) USART1 RX

# 6. Soporte técnico

Para contactarse con el soporte técnico puede comunicarse a:

Teléfono: xxxxxxxxxxx

Email: soportetecnico@gmail.com

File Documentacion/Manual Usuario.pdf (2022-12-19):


# Cartel Led Programable

## Manual de usuario

Técnicas Digitales II

Integrantes

Jonathan Yujra

Ovidio Argani

Cristian Torres

# Índice

Alimentación | 3
Encendido del dispositivo | 6
Funcionamiento | 7
Configuración a través de la Aplicación ATY app | 7
Configuración a través del teclado | 7
Rutina Modo 1: | 8
Rutina Modo 2: | 8
Rutina Modo 3: | 8
Apagado del dispositivo | 9
Soporte Técnico | 10
Solucionador de problemas | 10

# Alimentación

El dispositivo funciona a 5V. Para poder encenderlo necesita un transformador de 220V/5V AC-DC que pueda suministrar 5V al aparato. Pueden utilizarse cualquier tipo de cargador de smartphone que entregue a la salida esa salida de tensión. Precaución: Hay cargadores de carga rápida que entrega más de 5V a su salida, si utiliza esos cargadores podría ocasionar daños al dispositivo, recomendamos fijarse bien su salida antes de conectarlo.

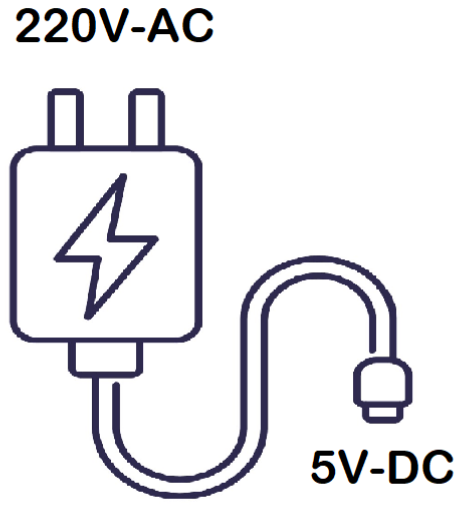
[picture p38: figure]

Fig.1: Transformador de 220V a 5V

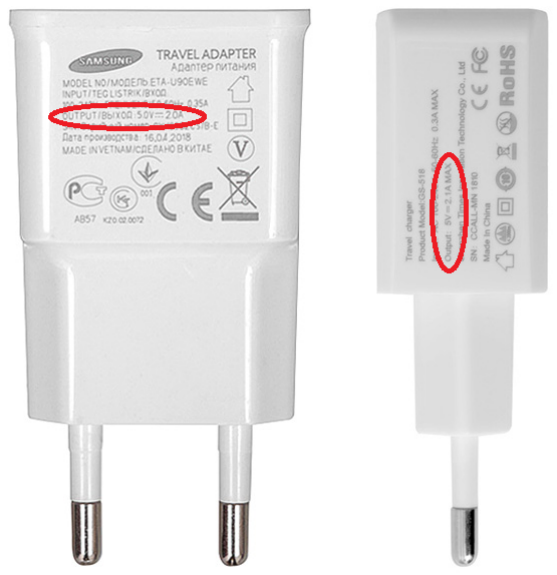
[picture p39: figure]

Fig.2: Ejemplo de transformador

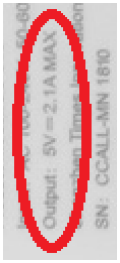
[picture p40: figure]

Fig.2: Datos transformador

Nota:

El aparato trae una batería interna que cumple la función de no apagar el reloj propio del sistema. No la retire.

# Encendido del dispositivo

El dispositivo se encenderá apenas se alimente. Una vez que enchufe el transformador el dispositivo iniciará mostrando un mensaje de bienvenida en la pantalla. Luego de unos segundos se procederá a ejecutar el MODO 1 (Ver el apartado de Funcionamiento para más detalles).

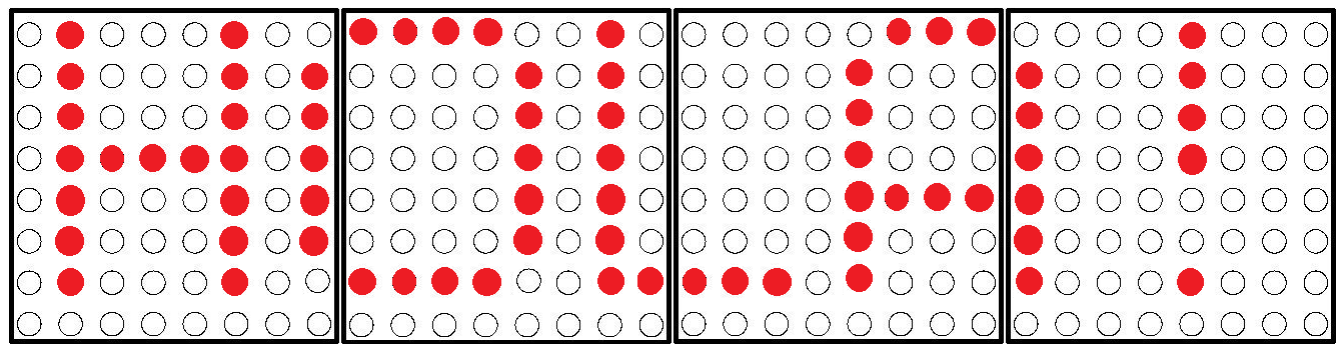
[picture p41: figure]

Fig.3: Mensaje de bienvenida en el cartel

El dispositivo tiene una rutina predeterminada: mostrará la fecha y hora que tuvo desde que fue actualizado de fábrica por última vez. Para actualizar o cambiar algún parámetro vea el apartado de funcionamiento del dispositivo.

# Funcionamiento

El dispositivo cuenta con una app disponible para Android y que puede descargarse desde la Play Store y que permitirá configurar el dispositivo como desee. También puede configurar el funcionamiento con los 3 botones que forman parte del aparato.

## Configuración a través de la Aplicación ATY app

La aplicación le permitirá, entre otras cosas, sincronizar la hora y la fecha actual de su smartphone con el dispositivo.

- Presione el botón “Ajustar Fecha” y/o “Ajustar Hora” para poder actualizar el reloj del sistema.
- Presione “Mensaje” para enviar un mensaje al dispositivo.
- Presione “Modo” para elegir entre los diferentes modos de funcionamiento del dispositivo.

## Configuración a través del teclado

El cartel cuenta con tres pulsadores con diferentes funciones para que se pueda modificar el funcionamiento sin necesidad de un dispositivo externo.

- Presione el pulsador 1 para cambiar los modos de funcionamiento del dispositivo.
- Si presiona 1 vez el cartel mostrará solo la fecha.
- Si presiona 2 veces el cartel mostrará solo la hora.
- Si presiona 3 veces el cartel mostrará la temperatura en el ambiente.
- Si vuelve a presionar el pulsador 1 vuelve a la rutina predeterminada.
- Presione el pulsador 2 para mostrar los mensajes cargados en el dispositivo
- Si presiona 1 vez el cartel mostrará el mensaje enviado por Bluetooth.
- Si presiona 2 veces el cartel mostrará el mensaje cargado desde la tarjeta SD.
- Si vuelve a presionar el pulsador 2 vuelve a la rutina predeterminada.
- Presione el pulsador 3 para cambiar la velocidad en la que el cartel muestra los mensajes.
- Si presiona 1 vez el cartel mostrará en una velocidad lenta
- Si presiona 2 veces el cartel mostrará en una velocidad media
- Si presiona 3 veces el cartel mostrará en una velocidad rápida
- Si vuelve a presionar el pulsador 3 volverá a la velocidad lenta

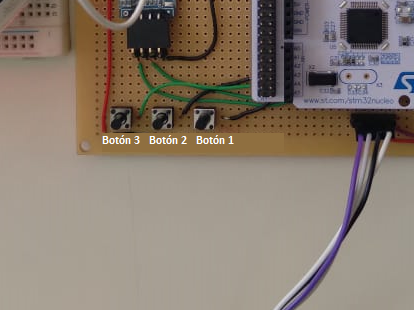
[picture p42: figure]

Fig. 4: Número de botones

Rutina predeterminada

El dispositivo cuenta con una rutina predeterminada ni bien es alimentado con 5V. La rutina consta de 3 mensajes que se muestran en la pantalla a velocidad media, y que se repiten en el siguiente orden:

1) Fecha
2) Hora
3) Temperatura

### Rutina Modo 1:

Cuando se selecciona el modo 1, el cartel solo mostrará la fecha.

### Rutina Modo 2:

Cuando se selecciona el modo 2, el cartel solo mostrará la hora.

### Rutina Modo 3:

Cuando se selecciona el modo 3, el cartel solo mostrará la temperatura.

# Apagado del dispositivo

Para apagar el dispositivo desconecte el aparato de la red eléctrica, la hora y la fecha no se perderán debido a la batería interna que tiene el dispositivo. Los mensajes cargados si se perderán. Cuando el cartel vuelva a estar enchufado el dispositivo mostrará nuevamente el mensaje de bienvenida seguido de la rutina predeterminada.

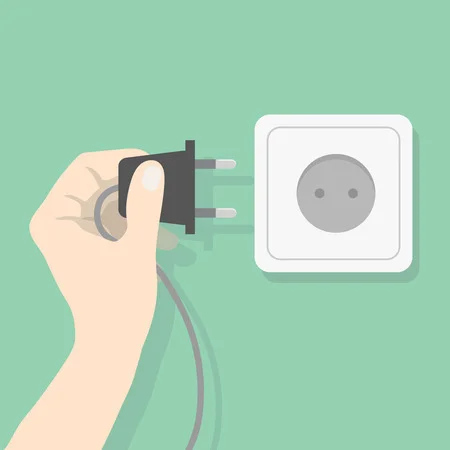
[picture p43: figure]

Fig. 5: Desconexión del transformador

# Soporte Técnico

## Solucionador de problemas

El dispositivo tiene una iluminación muy baja.

Es posible que el sensor de luz esté tapado por algún cuerpo u objeto.

El dispositivo tiene una iluminación muy alta.

Es posible que el ambiente esté muy iluminado o el sensor de luz esté siendo iluminado con una luz externa.

El dispositivo mide una temperatura muy alta

Es posible que el dispositivo esté cerca de una fuente de calor que impida al sensor de temperatura hacer una lectura fidedigna de la temperatura ambiente.

El dispositivo no cambia de mensaje a mostrar.

Presione el botón 1 para cambiar de modo de rutina o contacte al servicio técnico.

El dispositivo no guarda la hora y la fecha cuando se apaga.

El dispositivo puede haberse quedado sin batería interior. Cámbiela o contacte al servicio técnico.

Dadas las siguientes condiciones: detenga todo tipo de operación de inmediato. Desenchufe la unidad y contacte al centro de servicio técnico.

- Hay un fuerte ruido dentro del aparato
- Se emiten olores durante la operación
- El dispositivo calienta mucho
- El dispositivo fue expuesto al agua o a una fuente de calor.
- Calor anormal en el cable de suministro eléctrico o en el enchufe.

Teléfono Servicio técnico: 11-xxxx-xxxx

Email Servicio Técnico: serviciotecnico@gmail.com

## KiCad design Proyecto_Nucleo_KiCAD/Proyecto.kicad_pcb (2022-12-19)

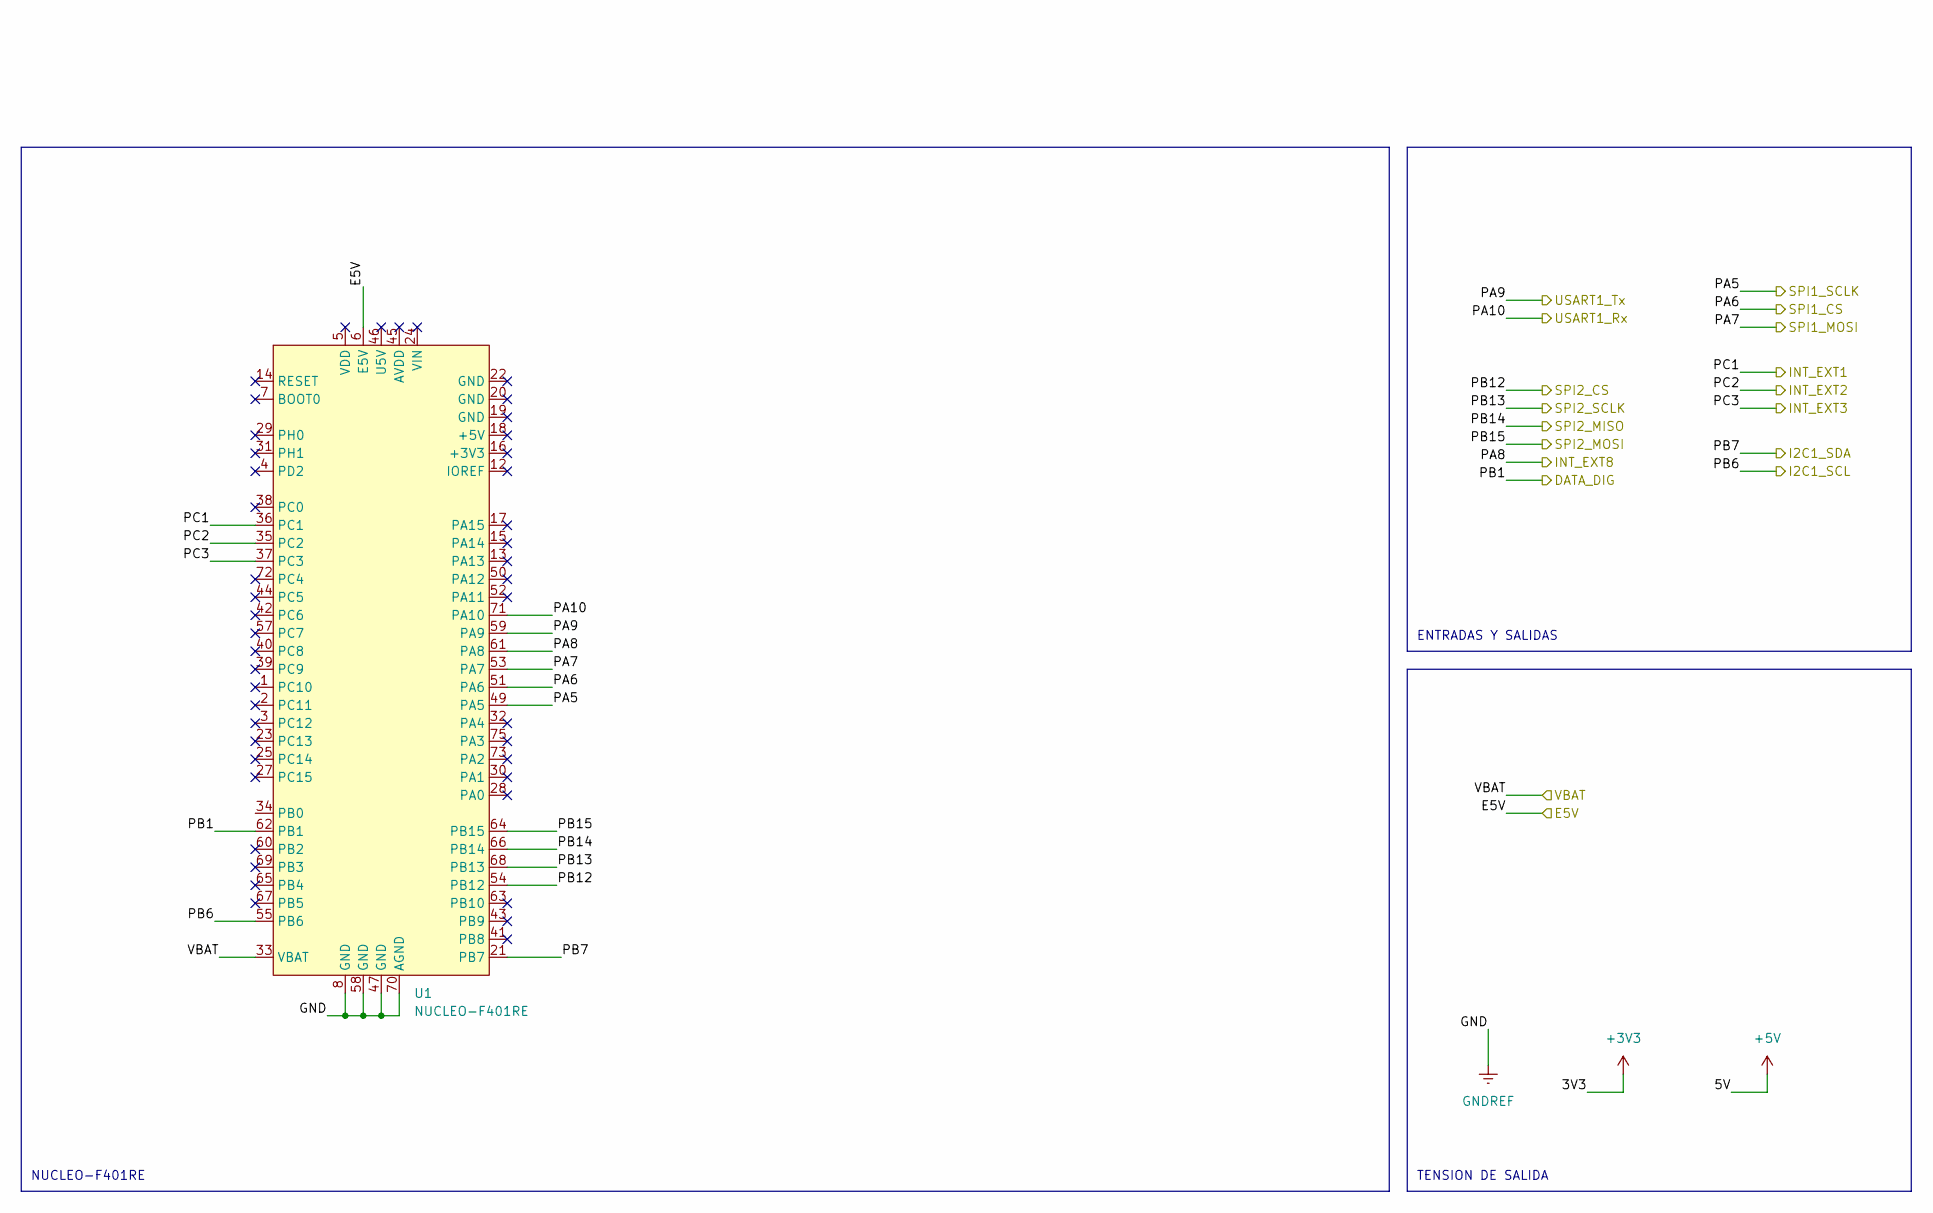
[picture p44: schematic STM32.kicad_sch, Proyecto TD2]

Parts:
U1: NUCLEO-F401RE; ST_NUCLEO-F401RE

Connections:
+5V: U1.6 (E5V); also elsewhere on the board
/EntradasSalidas/CS: U1.54 (PB12); also elsewhere on the board
/EntradasSalidas/MISO: U1.66 (PB14); also elsewhere on the board
/EntradasSalidas/MOSI: U1.64 (PB15); also elsewhere on the board
/EntradasSalidas/SCLK: U1.68 (PB13); also elsewhere on the board
/STM32/PA5: U1.49 (PA5); also elsewhere on the board
/STM32/PA6: U1.51 (PA6); also elsewhere on the board
/STM32/PA7: U1.53 (PA7); also elsewhere on the board
/STM32/PA8: U1.61 (PA8); also elsewhere on the board
/STM32/PA9: U1.59 (PA9); also elsewhere on the board
/STM32/PA10: U1.71 (PA10); also elsewhere on the board
/STM32/PB1: U1.62 (PB1); also elsewhere on the board
/STM32/PB6: U1.55 (PB6); also elsewhere on the board
/STM32/PB7: U1.21 (PB7); also elsewhere on the board
/STM32/PC1: U1.36 (PC1); also elsewhere on the board
/STM32/PC2: U1.35 (PC2); also elsewhere on the board
/STM32/PC3: U1.37 (PC3); also elsewhere on the board
/STM32/VBAT: U1.33 (VBAT); also elsewhere on the board
GNDREF: U1.8 (GND), U1.47 (GND), U1.58 (GND), U1.70 (AGND); also elsewhere on the board

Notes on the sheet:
ENTRADAS Y SALIDAS
NUCLEO-F401RE
TENSION DE SALIDA

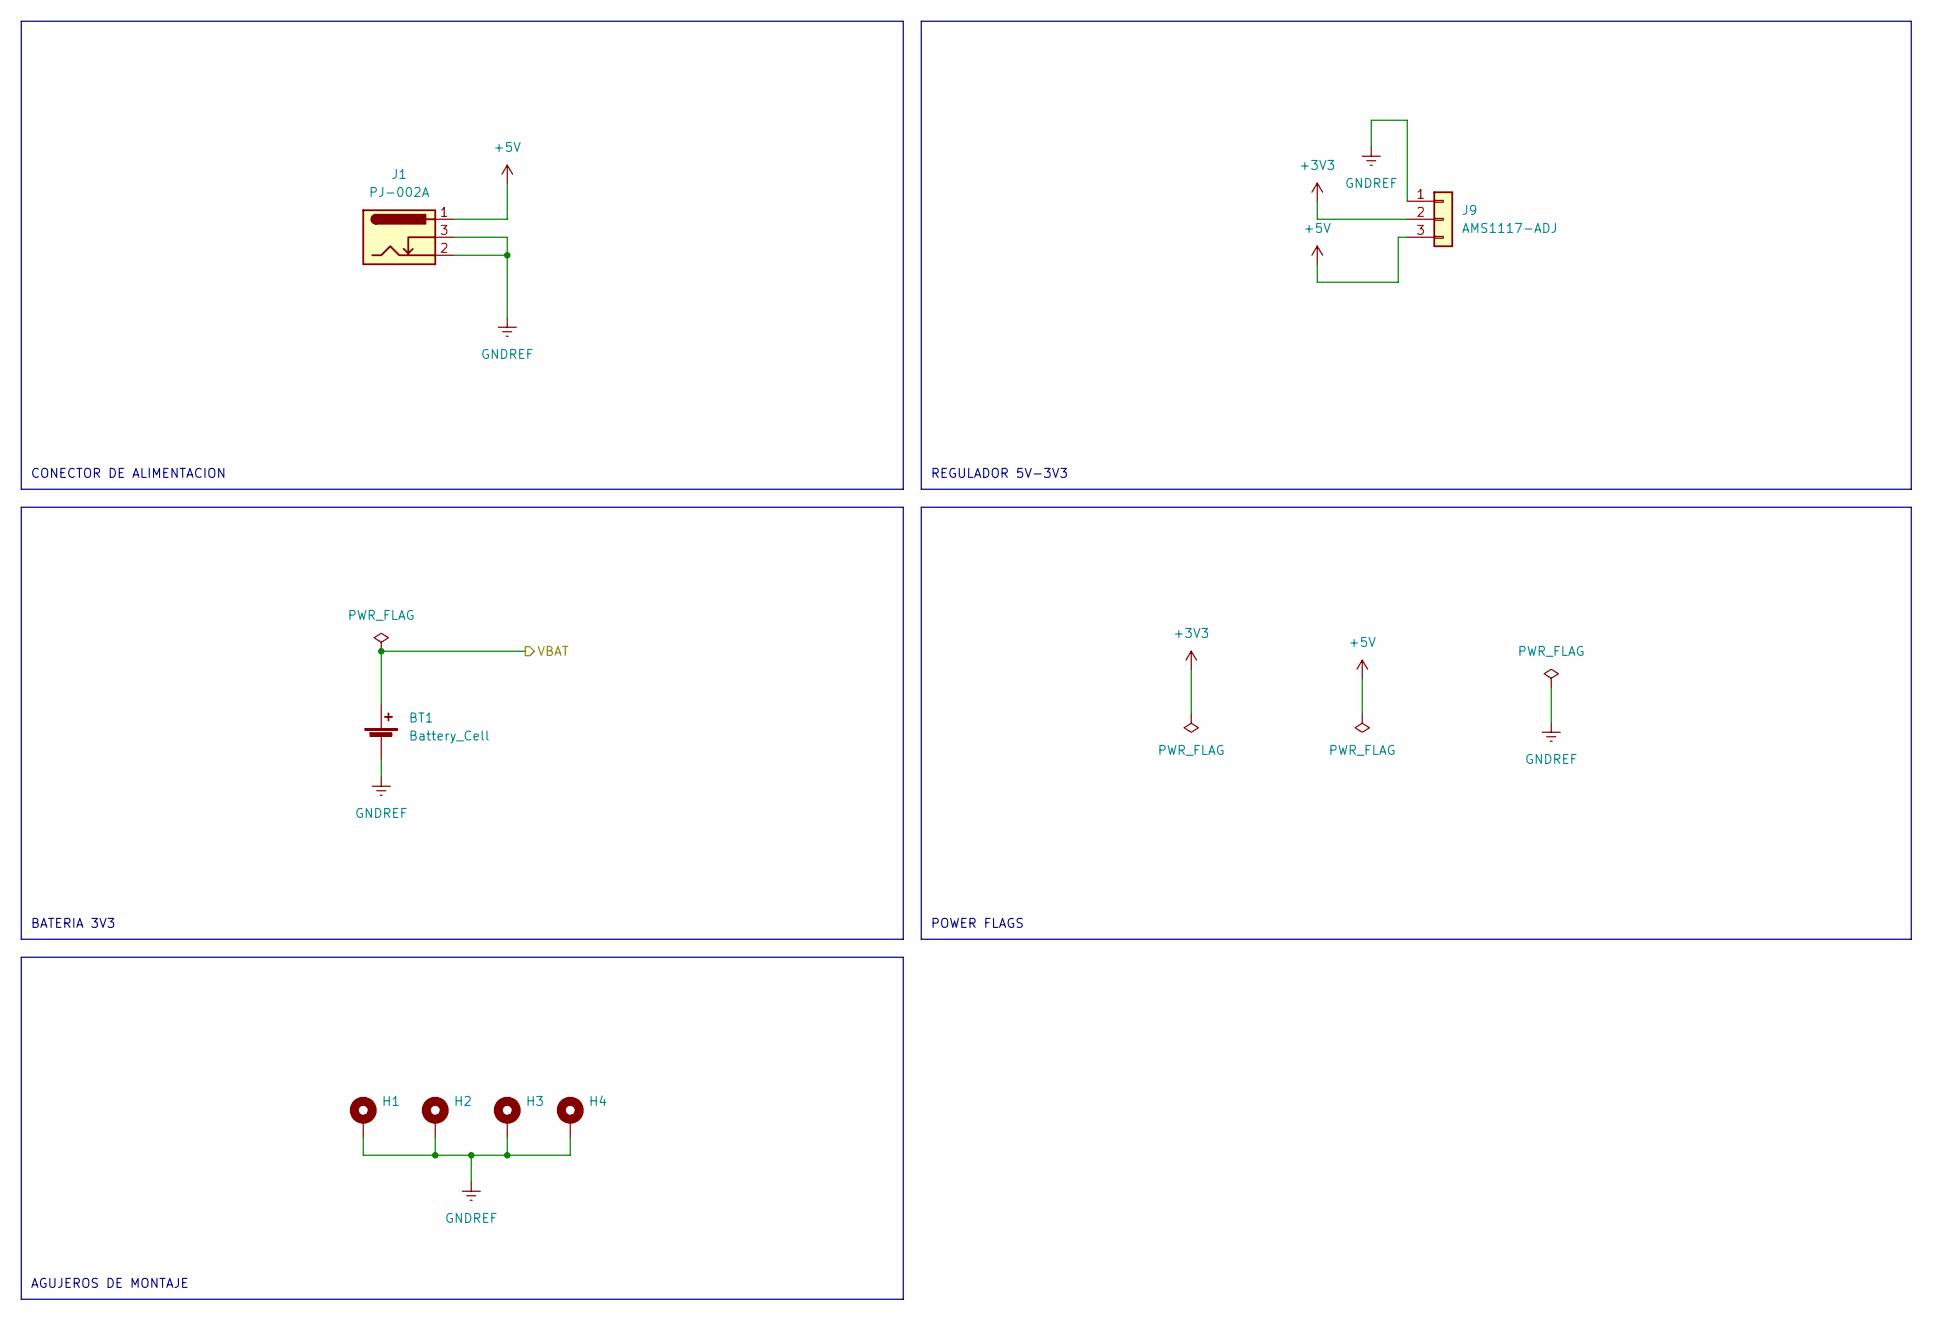
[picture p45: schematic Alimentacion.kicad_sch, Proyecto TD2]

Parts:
BT1: Battery_Cell; BatteryHolder_Keystone_103_1x20mm
H1, H2, H3, H4: MountingHole_Pad; MountingHole_2.5mm_Pad
J1: PJ-002A
J9: AMS1117-ADJ

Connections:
+3V3: J9.2; also elsewhere on the board
+5V: J1.1, J9.3; also elsewhere on the board
/STM32/VBAT: BT1.1 (+); also elsewhere on the board
GNDREF: BT1.2 (-), H1.1, H2.1, H3.1, H4.1, J1.2, J1.3, J9.1; also elsewhere on the board

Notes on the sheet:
CONECTOR DE ALIMENTACION
BATERIA 3V3
AGUJEROS DE MONTAJE
REGULADOR 5V-3V3
POWER FLAGS

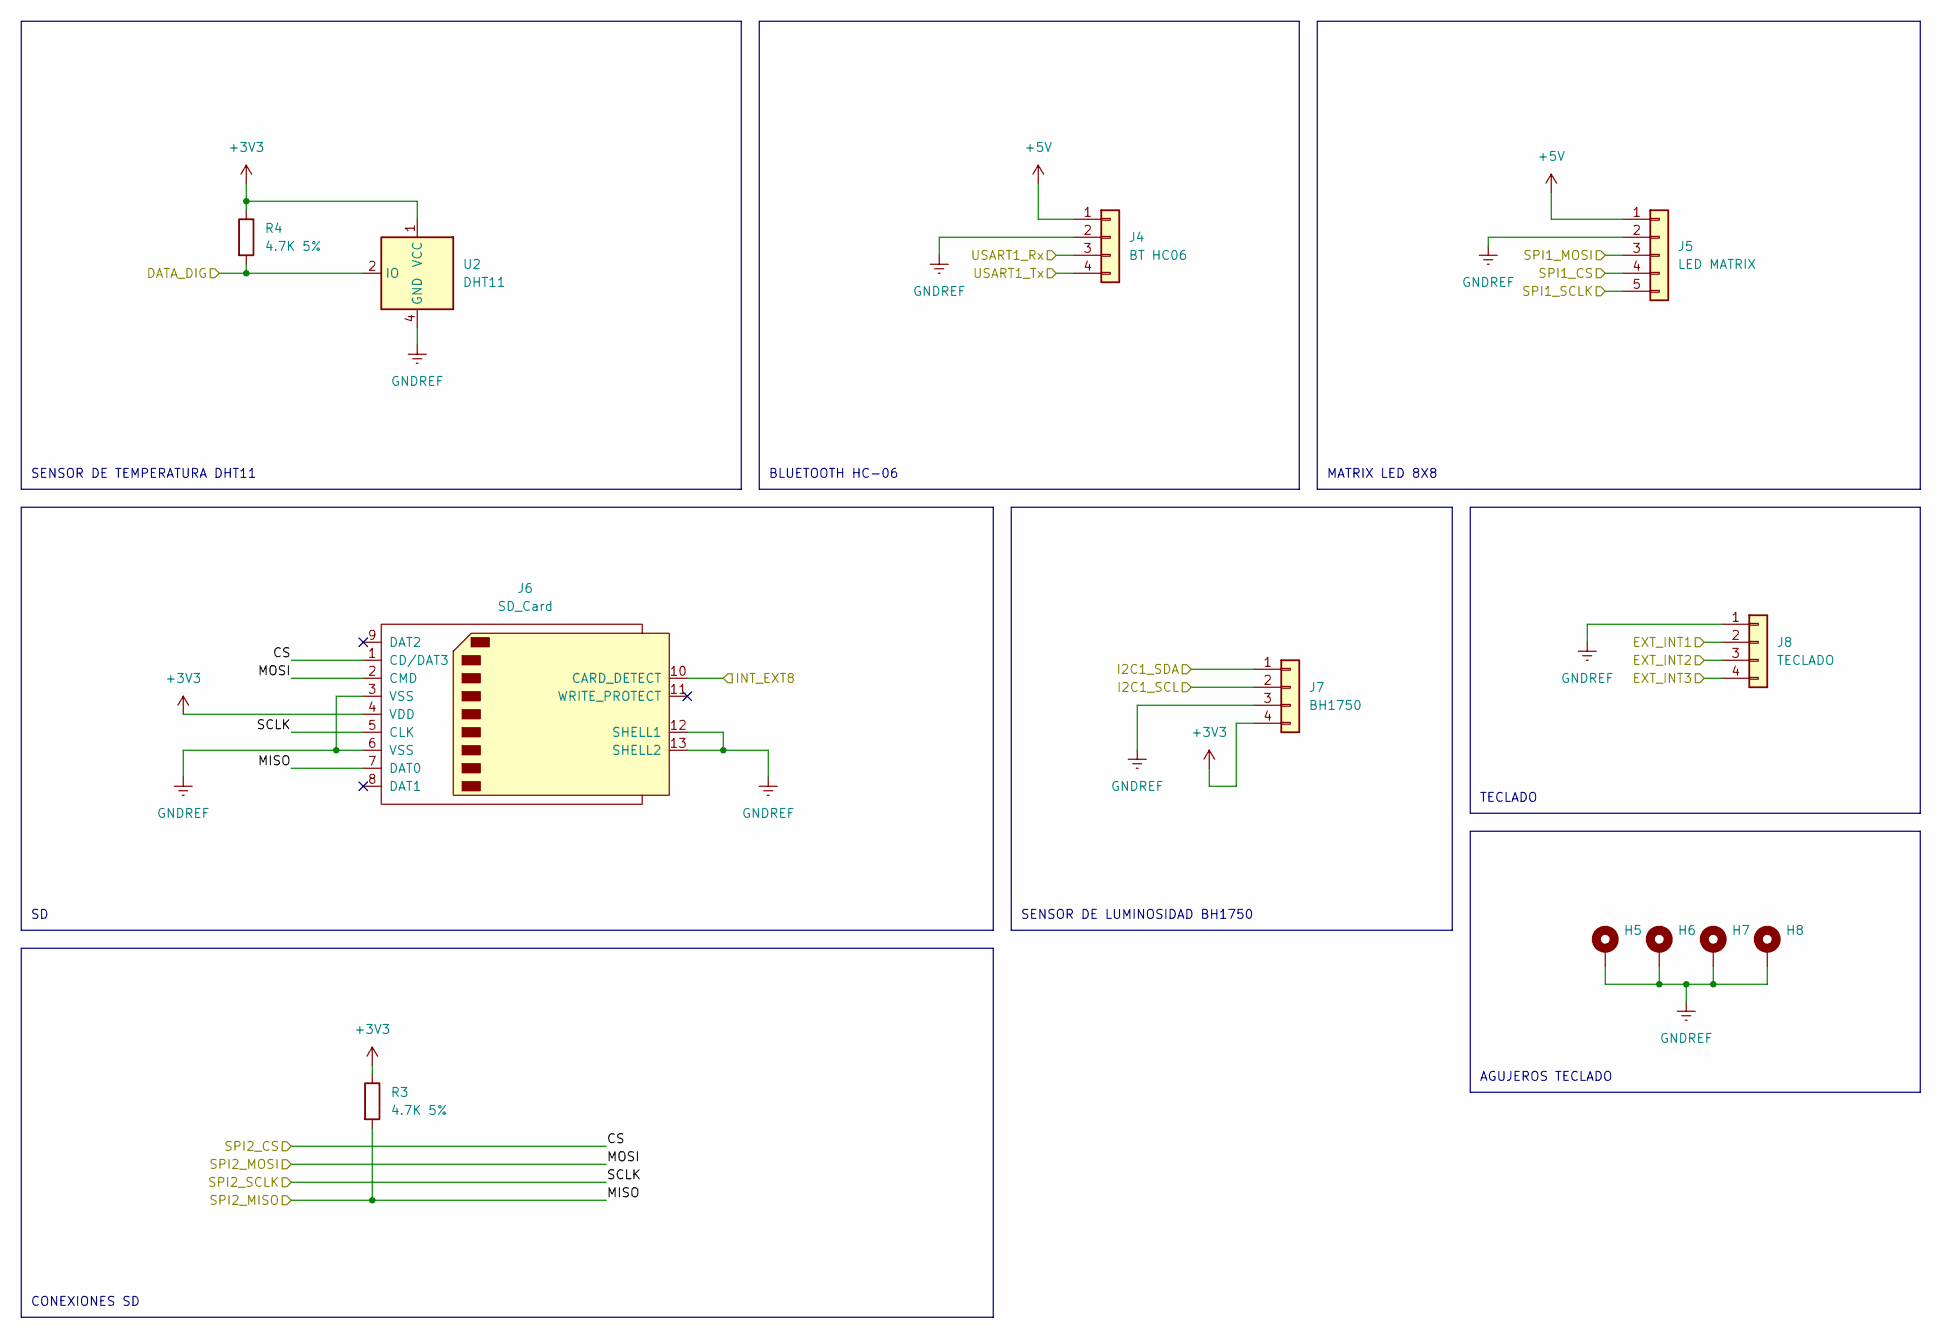
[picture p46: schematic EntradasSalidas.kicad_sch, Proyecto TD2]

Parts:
H5, H6, H7, H8: MountingHole_Pad; MountingHole_2.5mm_Pad
J4: BT HC06; HC06
J5: LED MATRIX; PinSocket_1x05_P2.54mm_Vertical
J6: SD_Card; footprint_SD_GSD09002SEU
J7: BH1750; PinSocket_1x04_P2.54mm_Vertical
J8: TECLADO; PinSocket_1x04_P2.54mm_Vertical
R3, R4: 4.7K 5%; R_Axial_DIN0207_L6.3mm_D2.5mm_P15.24mm_Horizontal
U2: DHT11; Aosong_DHT11_5.5x12.0_P2.54mm

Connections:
+3V3: J6.4 (VDD), J7.4, R3.1, R4.1, U2.1 (VCC); also elsewhere on the board
+5V: J4.1, J5.1; also elsewhere on the board
/EntradasSalidas/CS: J6.1 (CD/DAT3); also elsewhere on the board
/EntradasSalidas/MISO: J6.7 (DAT0), R3.2; also elsewhere on the board
/EntradasSalidas/MOSI: J6.2 (CMD); also elsewhere on the board
/EntradasSalidas/SCLK: J6.5 (CLK); also elsewhere on the board
/STM32/PA5: J5.5; also elsewhere on the board
/STM32/PA6: J5.4; also elsewhere on the board
/STM32/PA7: J5.3; also elsewhere on the board
/STM32/PA8: J6.10 (CARD_DETECT); also elsewhere on the board
/STM32/PA9: J4.4; also elsewhere on the board
/STM32/PA10: J4.3; also elsewhere on the board
/STM32/PB1: R4.2, U2.2 (IO); also elsewhere on the board
/STM32/PB6: J7.2; also elsewhere on the board
/STM32/PB7: J7.1; also elsewhere on the board
/STM32/PC1: J8.2; also elsewhere on the board
/STM32/PC2: J8.3; also elsewhere on the board
/STM32/PC3: J8.4; also elsewhere on the board
GNDREF: H5.1, H6.1, H7.1, H8.1, J4.2, J5.2, J6.3 (VSS), J6.6 (VSS), J6.12 (SHELL1), J6.13 (SHELL2), J7.3, J8.1, U2.4 (GND); also elsewhere on the board

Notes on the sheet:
BLUETOOTH HC-06
SENSOR DE TEMPERATURA DHT11
SENSOR DE LUMINOSIDAD BH1750
TECLADO
AGUJEROS TECLADO
CONEXIONES SD
MATRIX LED 8X8

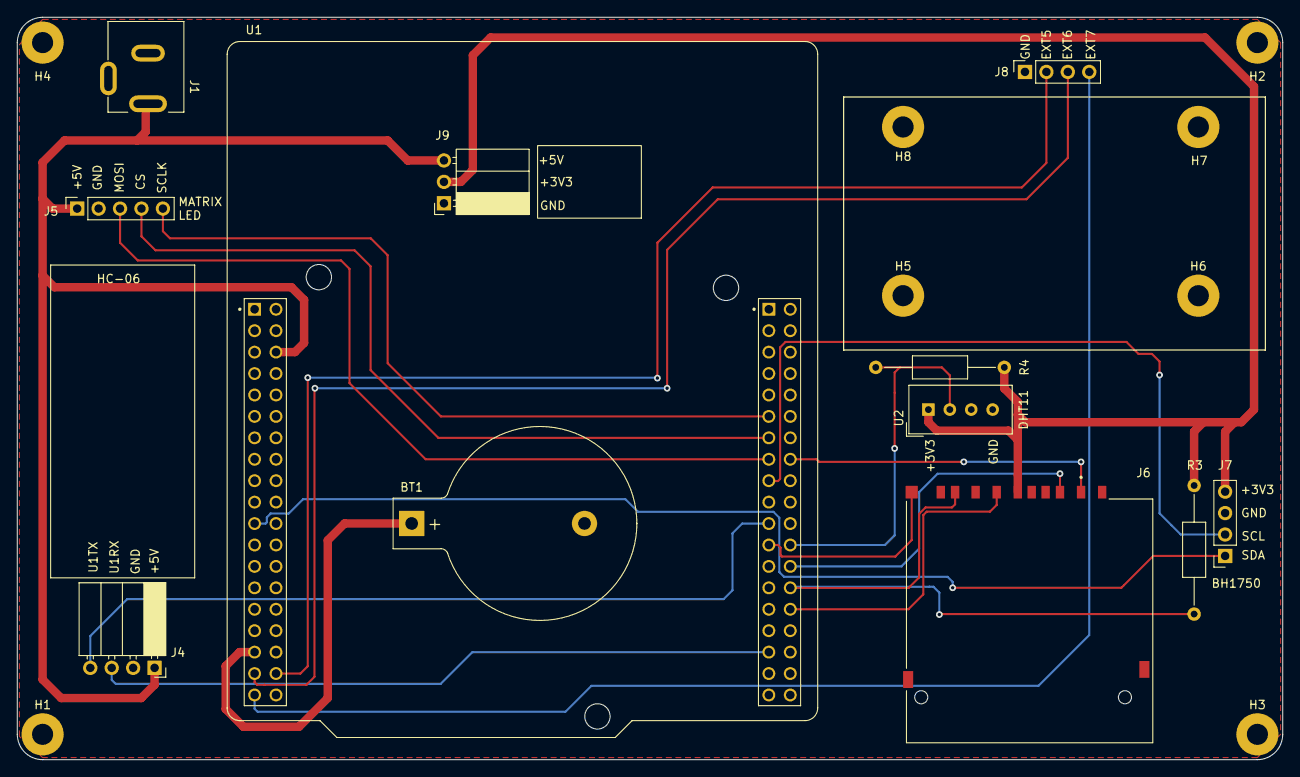
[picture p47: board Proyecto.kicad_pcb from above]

Board: 2 copper layers, 150.0 x 88.0 mm, 20 parts (0 on the bottom side), 20 nets.

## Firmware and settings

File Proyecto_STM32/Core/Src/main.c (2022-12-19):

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
/* Includes ------------------------------------------------------------------*/
#include "main.h"
#include "cmsis_os.h"
#include "fatfs.h"

/* USER CODE BEGIN PD */
//#define RTC_BKUP_DEFINE_CODE 0xBEBE
/* USER CODE END PD */

 I2C_HandleTypeDef hi2c1;

RTC_HandleTypeDef hrtc;

SPI_HandleTypeDef hspi1;
SPI_HandleTypeDef hspi2;

TIM_HandleTypeDef htim2;
TIM_HandleTypeDef htim3;
TIM_HandleTypeDef htim4;

UART_HandleTypeDef huart1;

osThreadId defaultTaskHandle;
/* USER CODE BEGIN PV */
uint8_t modo;
char mensaje_sd[STR_MAX_SD];
uint32_t timer_msg_sd;

CartelLed_TypeDef Cartel_Led;

xSemaphoreHandle sem_rx;
xSemaphoreHandle sem_push1;
xSemaphoreHandle sem_push2;
xSemaphoreHandle sem_push3;
xSemaphoreHandle sem_rutina_normal;
xSemaphoreHandle sem_rutina_alt;

//uint8_t dataRx[LONG_DATOS_BT];

BH1750_device_t* test_dev;
char MSG[33] = "HOLA!   "; // 33 lenght

uint8_t pulsador_apretado=0;
//uint8_t flag_rutina=0;

/* USER CODE END PV */

void SystemClock_Config(void);
static void MX_GPIO_Init(void);
static void MX_I2C1_Init(void);
static void MX_SPI1_Init(void);
static void MX_TIM4_Init(void);
static void MX_RTC_Init(void);
static void MX_USART1_UART_Init(void);
static void MX_TIM3_Init(void);
static void MX_SPI2_Init(void);
static void MX_TIM2_Init(void);
void StartDefaultTask(void const * argument);

/* USER CODE BEGIN 0 */

/*
void incializar_tareas (void);
void inicializar_perifericos(void);
*/

/* USER CODE END 0 */

/**
  * @brief  The application entry point.
  * @retval int
  */
int main(void)
{
  /* MCU Configuration--------------------------------------------------------*/

  /* Reset of all peripherals, Initializes the Flash interface and the Systick. */
  HAL_Init();

  /* Configure the system clock */
  SystemClock_Config();

  /* Initialize all configured peripherals */
  MX_GPIO_Init();
  MX_I2C1_Init();
  MX_SPI1_Init();
  MX_TIM4_Init();
  MX_RTC_Init();
  MX_USART1_UART_Init();
  MX_TIM3_Init();
  MX_SPI2_Init();
  MX_FATFS_Init();
  MX_TIM2_Init();
  /* USER CODE BEGIN 2 */
  //HAL_TIM_Base_Start(&htim3);
  inicializar_perifericos();
  inicializar_tareas();

  /* USER CODE END 2 */

  /* USER CODE BEGIN RTOS_MUTEX */
  /* add mutexes, ... */
  /* USER CODE END RTOS_MUTEX */

  /* USER CODE BEGIN RTOS_SEMAPHORES */
  /* add semaphores, ... */
  /* USER CODE END RTOS_SEMAPHORES */

  /* USER CODE BEGIN RTOS_TIMERS */
  /* start timers, add new ones, ... */
  /* USER CODE END RTOS_TIMERS */

  /* USER CODE BEGIN RTOS_QUEUES */
  /* add queues, ... */
  /* USER CODE END RTOS_QUEUES */

  /* Create the thread(s) */
  /* definition and creation of defaultTask */
  osThreadDef(defaultTask, StartDefaultTask, osPriorityNormal, 0, 128);
  defaultTaskHandle = osThreadCreate(osThread(defaultTask), NULL);

  /* USER CODE BEGIN RTOS_THREADS */
  /* add threads, ... */
  /* USER CODE END RTOS_THREADS */

  /* Start scheduler */
  osKernelStart();

  /* We should never get here as control is now taken by the scheduler */
  /* Infinite loop */
  /* USER CODE BEGIN WHILE */

  while (1)
  {
    /* USER CODE END WHILE */

    /* USER CODE BEGIN 3 */
  }
  /* USER CODE END 3 */
}

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
/* USER CODE BEGIN 4 */

void HAL_GPIO_EXTI_Callback(uint16_t GPIO_Pin)
{
	BaseType_t p;

	if(GPIO_Pin==PUSH1_Pin)
	{
		HAL_Delay(5);
		while(HAL_GPIO_ReadPin(PUSH1_GPIO_Port, GPIO_Pin)==0);
		HAL_Delay(5);
		pulsador_apretado=1;
		xSemaphoreGiveFromISR(sem_push1,&p);
		portEND_SWITCHING_ISR(p);
	}

	else if(GPIO_Pin==PUSH2_Pin)
	{
		HAL_Delay(5);
		while(HAL_GPIO_ReadPin(PUSH2_GPIO_Port, GPIO_Pin)==0);
		HAL_Delay(5);
		pulsador_apretado=2;
		xSemaphoreGiveFromISR(sem_push2,&p);
		portEND_SWITCHING_ISR(p);
	}

	else if(GPIO_Pin==PUSH3_Pin)
	{
		HAL_Delay(5);
		while(HAL_GPIO_ReadPin(PUSH2_GPIO_Port, GPIO_Pin)==0);
		HAL_Delay(5);
		pulsador_apretado=3;
		xSemaphoreGiveFromISR(sem_push3,&p);
		portEND_SWITCHING_ISR(p);
	}

	//xSemaphoreGiveFromISR(sem_push,&p);
	//portEND_SWITCHING_ISR(p);
}


/* USER CODE END 4 */

/* USER CODE BEGIN Header_StartDefaultTask */
/**
  * @brief  Function implementing the defaultTask thread.
  * @param  argument: Not used
  * @retval None
  */
/* USER CODE END Header_StartDefaultTask */
void StartDefaultTask(void const * argument)
{
  /* USER CODE BEGIN 5 */
  /* Infinite loop */
  for(;;)
  {
    osDelay(1);
  }
  /* USER CODE END 5 */
}

/**
  * @brief  Period elapsed callback in non blocking mode
  * @note   This function is called  when TIM1 interrupt took place, inside
  * HAL_TIM_IRQHandler(). It makes a direct call to HAL_IncTick() to increment
  * a global variable "uwTick" used as application time base.
  * @param  htim : TIM handle
  * @retval None
  */
void HAL_TIM_PeriodElapsedCallback(TIM_HandleTypeDef *htim)
{
  if (htim->Instance == TIM1) {
    HAL_IncTick();
  }
  /* USER CODE BEGIN Callback 1 */
  if (htim->Instance == TIM4) {
    MATRIX_TMR_OVF_ISR(htim);
  }
  /* USER CODE END Callback 1 */
}

/**
  * @brief  This function is executed in case of error occurrence.
  * @retval None
  */
void Error_Handler(void)
{
  /* USER CODE BEGIN Error_Handler_Debug */
  /* User can add his own implementation to report the HAL error return state */
  __disable_irq();
  while (1)
  {
  }
  /* USER CODE END Error_Handler_Debug */
}

#ifdef  USE_FULL_ASSERT
/**
  * @brief  Reports the name of the source file and the source line number
  *         where the assert_param error has occurred.
  * @param  file: pointer to the source file name
  * @param  line: assert_param error line source number
  * @retval None
  */
void assert_failed(uint8_t *file, uint32_t line)
{
  /* USER CODE BEGIN 6 */
  /* User can add his own implementation to report the file name and line number,
     ex: printf("Wrong parameters value: file %s on line %d\r\n", file, line) */
  /* USER CODE END 6 */
}
#endif /* USE_FULL_ASSERT */

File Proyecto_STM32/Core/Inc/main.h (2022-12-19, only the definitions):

#define PUSH1_Pin GPIO_PIN_1
#define PUSH1_GPIO_Port GPIOC
#define PUSH1_EXTI_IRQn EXTI1_IRQn
#define PUSH2_Pin GPIO_PIN_2
#define PUSH2_GPIO_Port GPIOC
#define PUSH2_EXTI_IRQn EXTI2_IRQn
#define PUSH3_Pin GPIO_PIN_3
#define PUSH3_GPIO_Port GPIOC
#define PUSH3_EXTI_IRQn EXTI3_IRQn
#define USART_TX_Pin GPIO_PIN_2
#define USART_TX_GPIO_Port GPIOA
#define USART_RX_Pin GPIO_PIN_3
#define USART_RX_GPIO_Port GPIOA
#define SPI2_CS_Pin GPIO_PIN_12
#define SPI2_CS_GPIO_Port GPIOB
#define SD_CD_Pin GPIO_PIN_8
#define SD_CD_GPIO_Port GPIOA
#define TMS_Pin GPIO_PIN_13
#define TMS_GPIO_Port GPIOA
#define TCK_Pin GPIO_PIN_14
#define TCK_GPIO_Port GPIOA
#define SWO_Pin GPIO_PIN_3
#define SWO_GPIO_Port GPIOB
#define RTC_BKUP_DEFINE_CODE 0xBEBE

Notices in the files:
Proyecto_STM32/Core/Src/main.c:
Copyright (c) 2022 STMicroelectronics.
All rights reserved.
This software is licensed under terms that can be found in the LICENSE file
